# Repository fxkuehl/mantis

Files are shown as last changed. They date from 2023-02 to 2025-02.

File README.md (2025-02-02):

# Mantis hex ergo keyboard

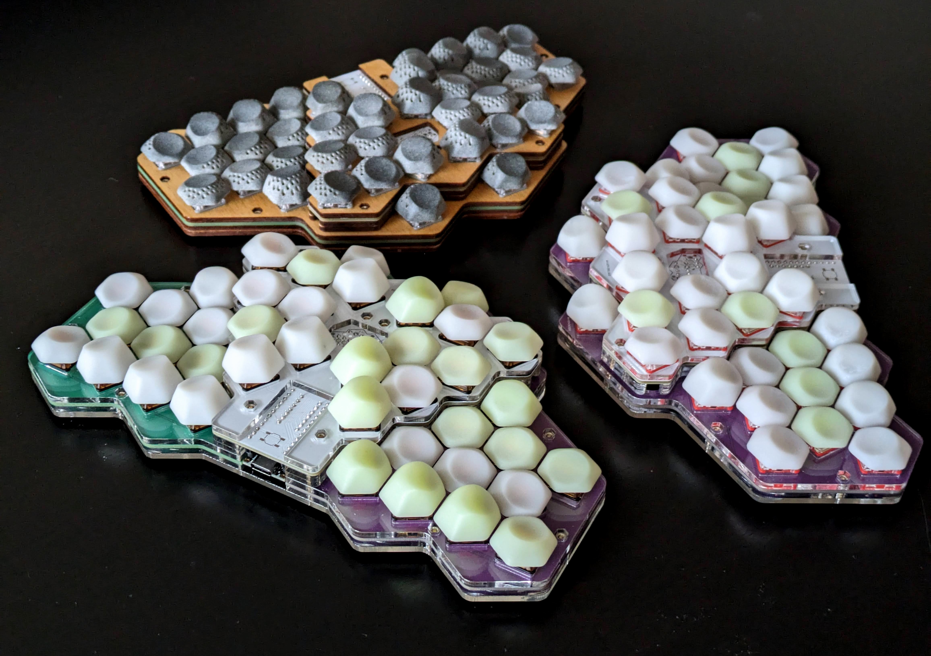
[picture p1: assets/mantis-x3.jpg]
>
>_Three different builds of Mantis v0.3.3, experimenting with different case and key cap materials_

## Contents

Mantis is an ergonomic keyboard designed around hexagonal keys.

This repository contains Ergogen, KiCad and OpenSCAD files for the PCBs, case and key caps, as well as a [build guide](./buildguide.md). You can print a [one-page reference and quick start guide](https://github.com/fxkuehl/mantis/blob/main/keymap.pdf) of the default keymap.

Mantis is approaching the end of the prototyping phase, currently at version v0.3.3. You can check the git history for older prototype versions.

Mantis v0.3.3 consists of three PCBs. Two identical [bottom PCBs](https://github.com/fxkuehl/mantis/raw/main/pcb/gerber/mantis-v0.3-bottom.zip) are reversible. The [central PCB](https://github.com/fxkuehl/mantis/raw/main/pcb/gerber/mantis-v0.3.3-top.zip) is stacked on top with M2 standoffs and headers to create an approximation of two tented, shallow key wells together with the [sculpted 3D printed keycaps](https://github.com/fxkuehl/mantis/tree/main/keycap) and the rotation of switches.

v0.3.3 also includes [DXF files](https://github.com/fxkuehl/mantis/tree/main/plates/v0.3.3) for laser-cut plates. I have built keyboards with 3mm thick acrylic and birch plywood plates, manufactured at Hot Pop Factory in Toronto.

## Build Guide

See the [complete build guide](./buildguide.md) for detailed instructions and all the tools, materials, and parts required.

## Firmware and Keymap

Firmware is available in my [QMK fork](https://github.com/fxkuehl/qmk_firmware/tree/mantis-vial-v0.3/keyboards/mantis). It is now based on the Vial version of QMK, so you can use the [Vial](https://get.vial.today/) GUI to customize the keymap more easily.

There is also a [ZMK shield](https://github.com/Silcantar/zmk-mantis). Thanks to Github user [Silcantar](https://github.com/Silcantar/) for creating it and [bringing](https://github.com/fxkuehl/mantis/issues/3) it to my attention.

# Concept

Mantis is a compact unibody ergo keyboard approximating 15° tented, shallow key wells using two layers of flat PCBs and custom sculpted hexagonal key caps. The hex grid naturally results in 30° hand rotation and aggressive column stagger. Hexagonal keys can rotate in 60° increments, which enables a decent approximation of key wells with only one or two unique keycap shapes. Existing 3x5+3 split layouts with 36 keys should be adaptable for this keyboard.

I recorded a short [YouTube video](https://www.youtube.com/watch?v=Rh3bqSVHcbg) to demonstrate the usability and comfort.

Layout diagram
>_Mapping QWERTY to the Mantis layout with staggered columns rotated 30° inwards_

Due to the way that columns of hexagonal keys are staggered, the index fingers only have five keys, while the pinkies can get one extra key that is comfortable to reach with splay. This requires some layout modifications when mapping QWERTY (or your favourite alternative layout) to this keyboard.

I wrote a [longer article](https://kbd.news/Mantis-Hexagonal-Keys-in-Ergonomic-Keyboards-2202.html) about the ergonomics of the layout and the motivation for trying hexagonal keys for the [kbd.news](https://kbd.news/) 2023 advent calendar.

## Evolution

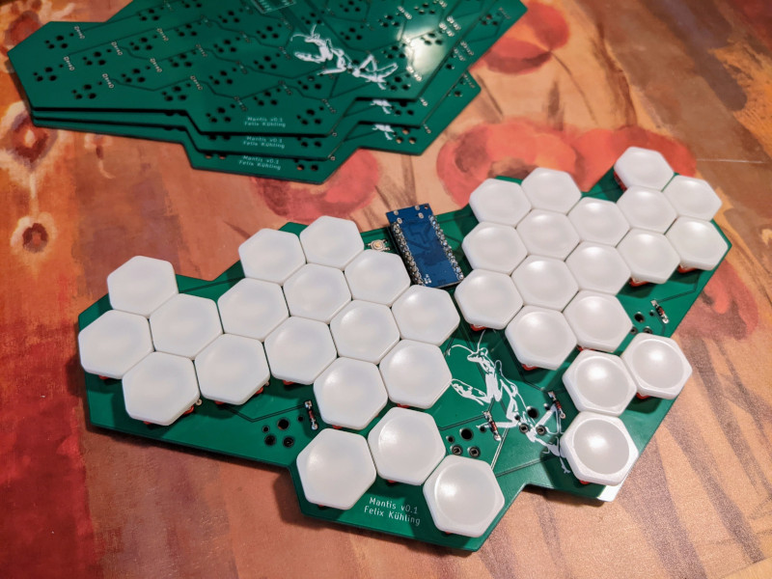
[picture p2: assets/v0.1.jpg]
v0.1
>

The first prototype v0.1 was inspired by [FK Keycaps HEX](https://fkcaps.com/keycaps/hex) keycaps. It served as a proof of concept of an ergonomic layout using hexagonal keys and gave me ideas for future revisions. This lead to the raised center and modified pinkie key layout in v0.2.

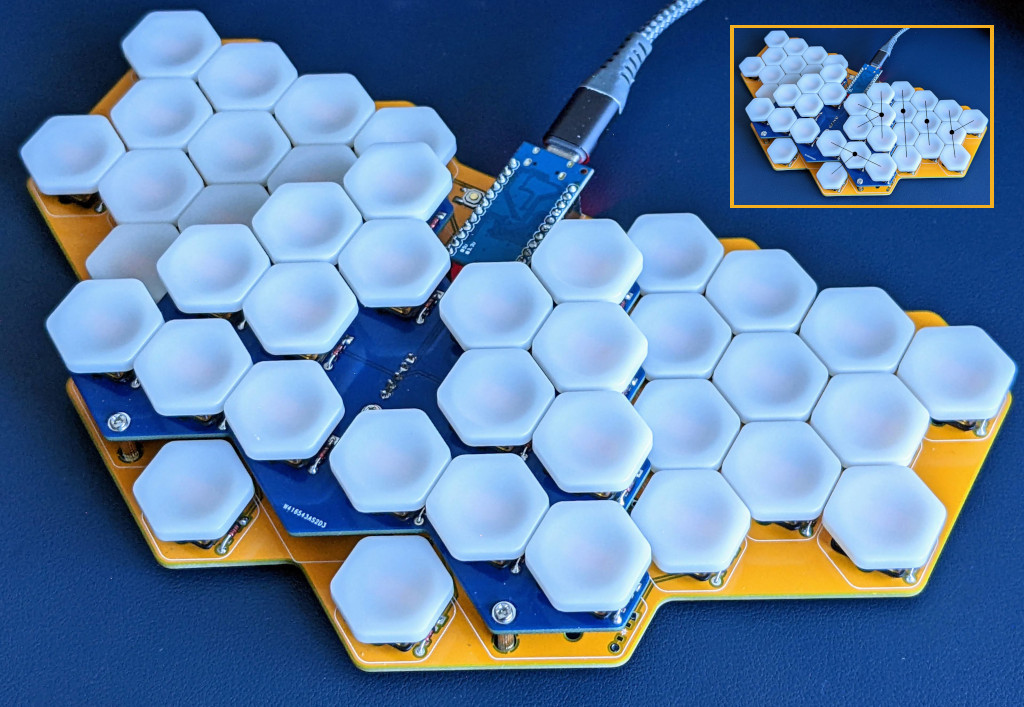
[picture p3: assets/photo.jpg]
v0.2
>

The raised center in v0.2 adds tenting and makes the index finger keys easier to reach. It also improves the spacing an usability of the thumb keys. I experimented with different mounting methods for stacking two PCBs, and tried different heights. Although usable and my daily driver for several months, this version still had problems with finger travel distance and accidental adjacent key presses.

These problems were addressed in v0.3 with a custom 3D-printed key profile and switch rotation. v0.3 also added per-key RGB backlight and a laser-cut sandwich case. The latest PCB and case version v0.3.3 has some refinements of the fit, changes the rotation of two keys on the upper PCB and adds support for RGB LEDs with 3.3V controllers.

The name Mantis comes from the shape of the PCB resembling a mantis head and the hexagonal keys suggesting compound eyes.

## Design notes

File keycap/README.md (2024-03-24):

# Mantis Keycap Recommendations

I created two types of keycaps:

- [Flat with 15° tilt](./keycap-v2-15-solid.stl) for most keys (24 keys per keyboard)
- [Tall with 28° tilt and flattened top](./keycap-v3-28-solid.stl) for top row and some of the thumb keys (16 keys per keyboard)

The two links above take you to the STL files to use for 3D printing. There are [additional](./keycap-v2-15.stl) [variants](./keycap-v3-28.stl) with small holes for letting LEDs shine through. Light resin keycaps are translucent enough without the holes. But they are needed if you want to see RGB lights with black resin, nylon or other opaque plastic keycaps.

There are also STL files that combine 10 keycaps in a single STL model, which may allow cheaper printing with some manufacturers, depending on their minimum per-part cost. This may negatively affect the quality of the print. See [this article](https://kbd.news/Mantis-keycaps-2157.html) for more details.

It is possible to build an entire keyboard with only the 15° keycaps. The top row will be a slightly longer reach, but it will still be quite comfortable to type on.

My original plan was to use the tall 28° keycaps on the bottom row as well. But I find that flat keys work better for curling my fingers and lead to less finger movement.

Finally, Mantis is still compatible with [FK Keycaps HEX](https://fkcaps.com/keycaps/hex) keycaps. These are the keycaps that inspired me to design this keyboard in the first place. But I would not recommend them for the most comfortable and efficient typing experience any more.

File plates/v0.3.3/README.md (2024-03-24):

# Mantis Case Plates

The cheapest way to build a Mantis is without a case. However, to protect the electronic components, and to get a more solid feel and sound, it is better to add a case. The case design for v0.3.3 uses laser cut plates of 3mm thickness. You can use different thickness, but that will also change the height of the standoffs and headers you need. I have built a few keyboard with clear acrylic plates, which looks nice with RGB LEDs and shows off the colors of the PCBs. I used birch plywood in another build for a slightly more rustic look.

To help with cost-effective manufacturing I created several DXF files in this folder that combine all the plates for [one](./plates.dxf), [two](./plates2x.dxf) or [four](./plates4x.dxf) keyboards in a single efficient layout. The four-keyboard layout fits on 60x90cm sheets of material and got the case cost for my latest builds down to about $50 CAD per keyboard from a local laser cutting shop.

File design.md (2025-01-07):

# Mantis Keyboard Design Evolution

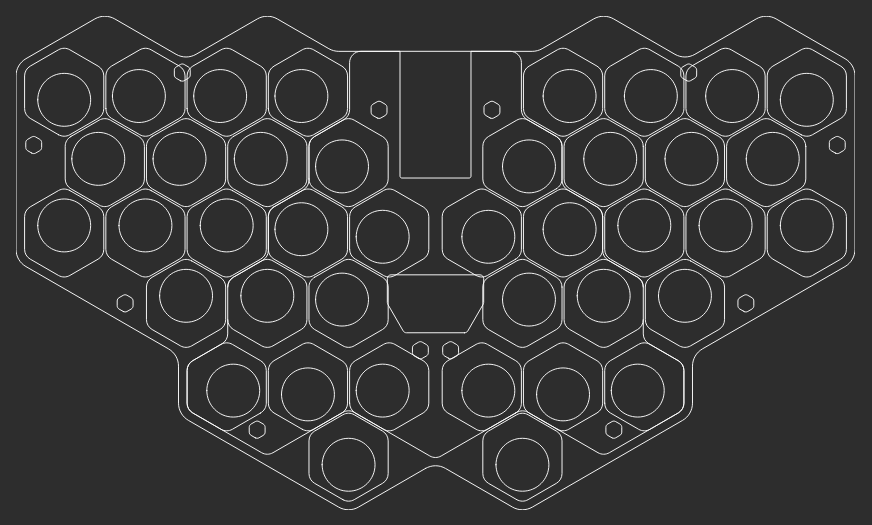
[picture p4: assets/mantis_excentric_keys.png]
>

>_Read the image captions below for the TL;DR ..._

When I started working on Mantis I was intrigued by the look of [hexagonal key caps](https://fkcaps.com/keycaps/hex) and their potential to create an ergonomic layout that follows from the hexagonal packing of keys. I learned to use [Ergogen](https://ergogen.cache.works/), [KiCad](https://www.kicad.org/), and eventually [OpenSCAD](https://openscad.org/), one prototype led to the next, and with v0.3 I may have created the lowest-profile, best-sounding, easiest to assemble tented unibody split keyboard with a key well that also happens to have hexagonal keys.

What all Mantis prototypes have in common are some of the original design ideas and methods used:

- Key spacing for [FK Keycaps Hex Keycaps](https://fkcaps.com/keycaps/hex)
- Unibody, 40 keys, compatible with 36-key layouts
- Column stagger and rotation of the keyboard halves resulting from the hexagonal key shape
- Layout and outlines designed with [Ergogen](https://ergogen.cache.works/)
- PCBs finished with [KiCad](https://www.kicad.org/)
- [QMK](https://qmk.fm/) firmware

Thanks to [PCBWay](https://www.pcbway.com/) for sponsoring v0.2 and v0.3 PCB production!

## February 2023 - v0.1: Proof of Concept

>v0.1

>_Hexagonal keys? Neat! I bet I can make an ergonomic unibody keyboard layout with that, where the column stagger and hand rotation follow organically from the shape of the keys. Let's build it and find out! Throw in some pinky splay too, while we're at it. With the keys resembling compound eyes, it kind of looks like the face of a praying mantis._

Version 0.1 was a proof of concept that hexagonal keys could be used to create an ergonomic unibody split keyboard layout that is actually usable. The shape of the keys results in a strong column stagger with the hands rotated 30° compared to a straight ortho-linear layout. The hexagonal packing of keys brings the columns closer together and results in the same distance of all keys from the home key of the same finger. Compared to "normal" 3x5 layouts, the index fingers lose one key that moves to the pinky instead. The pinkies get some splay in the top row.

Hot-swap sockets for switches and controller allowed easy reuse on later prototypes.

My [Reddit post](https://www.reddit.com/r/ErgoMechKeyboards/comments/116xqfr/first_prototype_of_my_ergonomic_keyboard_design/) prompted quite a spectrum of reactions (paraphrasing):

- Sexy!
- Something from an alien space ship ...
- Is this row staggered or column staggered?
- Where the heck is the home row?
- It makes my brain/hands hurt.
- Why would you want this?
- Nothing about this is ergonomic.

My verdict: v0.1 was actually usable. Coming from a Cantor Remix with 36 keys, I quickly adapted to the Mantis layout. The column stagger felt good. The pinky splay in the top row was a bit unfamiliar at first, but not bad. It took me a week or two to fully adjust to a modified Colemak-DH layout with 5 index-finger and 4 pinky keys. The large angle of the keyboard halves allows the wrists to be straight with the elbows resting on the arm-rests and the shoulders relaxed. A video of my typing looked relaxed with minimal hand and wrist movement.

v0.1 also revealed a few problems in use:

- The fourth thumb key was unusable (as expected)
- The other three thumb keys were too close together in their arc
- The outer home row pinky key was uncomfortable to reach
- Finger travel distance within the columns was quite large, though not excessive with only 3 rows to reach
- The flat key profile can lead to accidental adjacent key presses (I had the same problem with MBK key caps on my Cantor Remix)

## March 2023 - v0.2: Mantis Goes 3D

>v0.2

> _v0.1 was actually usable and comfortable. The pinky splay worked, but the outer home row pinky keys were a bit uncomfortable to reach, so v0.2 rearranges the pinky keys. Also the thumb keys were a bit close together and the optional 4th thumb key wasn't usable. Raising the center keys can fix those thumb cluster issues while adding some tenting and an approximation of a key well all at once. There are more things I want to try, but this is enough change for another prototype. Stacking two PCBs allows playing with some fun color schemes! Not all mantises are green ..._

v0.2 takes some inspiration from the [Thumbs Up!](https://www.reddit.com/r/ErgoMechKeyboards/comments/z4qdgr/thumbs_up_v2_keyboard/) keyboard. By raising the center keys, an approximation of a key well is created. Going into the 3rd dimension also offers a neat solution to the thumb cluster issues without compromising on the hexagonal key layout: By lowering the front-most thumb key, it creates a larger separation of the three keys in the arc and it makes the fourth thumb key above it usable. Other benefits:

- Index fingers can reach their keys more easily
- 10mm rise results in about 15° tenting angle to make the wrists more comfortable
- Home position is easy to find by touch

v0.2 also changed the layout of the pinky keys to avoid uncomfortable stretching to the side, which resulted in a slightly more compact layout. The bottom PCB still has all the switch footprints, so it could still be used to build a flat keyboard.

I built two prototypes to experiment with different heights and assembly methods. The top and bottom PCBs can be connected with only the headers. Optional M2 stand-offs can be used to adjust the height and make the assembly more stable. A high-profile version with 12mm rise uses 8mm headers. Adding 10mm stand-offs made it sturdier. A low-profile version with 6.6mm rise uses low profile sockets, diode legs as pins and 5mm stand-offs. The ideal may be somewhere in the middle using 8mm stand-offs and maybe 5mm headers from Adafruit.

For this version I created and over time refined a unique keymap loosely based on my earlier Kolibri layout. It takes advantage of the hexagonal layout for the positioning of arrow keys and F-keys, with numbers on the home row and the ability to switch between modified QWERTY and Colemak-DH layouts with a key combination.

## July 2023 - v0.3: Sculpted Key Caps, RGB, Case Plates

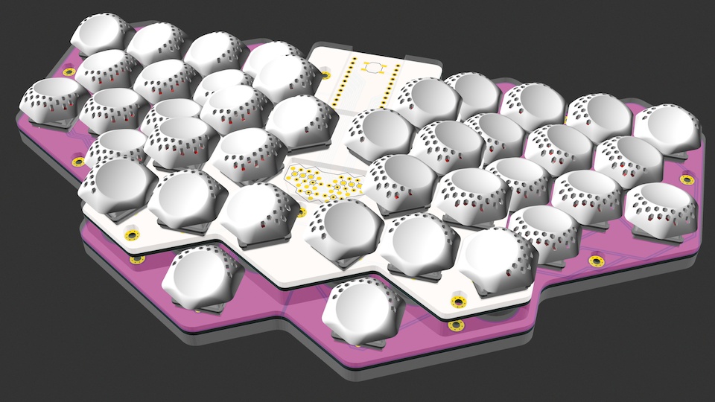
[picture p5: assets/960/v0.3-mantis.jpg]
v0.3 render
>

> _v0.2 was pretty good for daily use. I actually built two of them for home and the office, and I even took one with me while travelling. But there are some problems left to fix, and bling that needs to be added. So here comes a big redesign with lots of attention to detail: Sculpted keys optimized for touch typing, per-key RGB, an acoustically optimized acrylic case, and a split/reversible bottom PCB to reduce cost. Since I already learned OpenSCAD to create the key cap, why not render a preview of the whole keyboard with it? BTW, there is only a single key cap profile here. The shallow key well is achieved by rotating the switches in 60° increments. Try that with square keys!_

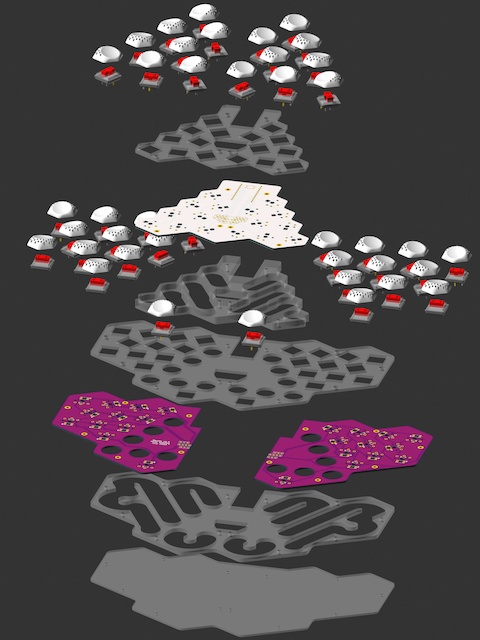
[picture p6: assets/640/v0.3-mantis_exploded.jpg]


The original flat Hex key caps from FK Keycaps were designed for [music keyboards](https://fabacademy.org/2020/labs/opendot/students/sol-bekic/projects/keyboard/) and [macro pads](https://fkcaps.com/keyboards/0xC.pad). While v0.3 is still compatible with the flat Hex key caps, fixing the problems with accidental key presses and finger travel distance called for the design of 3D-printable [sculpted key caps](https://github.com/fxkuehl/mantis/blob/main/keycap/keycap.stl) with features optimized for ergonomic touch typing:

- Smaller target area with a spherical dish and defined edge
- Tilted, excentric dish oriented toward the direction of finger movement to reduce finger travel and ensure smooth key actuation by directing force towards the center of the switch stem
- Sloping sides to create more separation between adjacent keys, reducing accidental key presses
- Smooth transition from the front of the dish to the edge of the key to make it comfortable for the thumbs

The key profile is designed in OpenSCAD to make it parametric and easy to adjust and optimize. Using the general polyhedron primitive makes it possible to describe the organic shape with curved, sloping sides creating a smooth transition from the rim of the tilted spherical dish to the rounded hexagon outline of the key. A Minkowski sum with a half sphere is used to generate an even wall thickness. To allow per-key LEDs to work with opaque materials, the outside slope near the switch's LED hole features perforations to let light shine through and reflect indirectly in all key orientations.

The tilt angle of the spherical dish is 15° to match the intended tenting angle of the keyboard on the home row. On the other rows, the keys are rotated differently to match the direction of finger travel. This is achieved by rotating the switches and their PCB footprints in 60° increments. Thus only a single key cap profile is sufficient to approximate a shallow key well. Even with the sculpted profile and a 15° tilt, the keys are only 2mm taller than the original flat Hex key caps.

In addition to per-key RGB backlight, v0.3 adds a case by sandwiching laser-cut plates with the PCBs, held together with M2 stand-offs. The mid-layers are designed to optimize the acoustics of the keyboard. The resonant spaces in the top and bottom of the case are connected through openings in the PCBs and switch plates such that each keyboard half has a long channel (~50cm) winding under its keys, open to the outside on one end. The low resonant frequency (~170Hz) is meant to modulate the sound of the key strokes for a "thocky" effect. To make a continuous channel possible, hot-swap sockets had to be sacrificed; v0.3 supports only soldered switches.

The bottom PCB is split and reversible to reduce manufacturing cost. The diodes and LEDs are surface mounted on the bottom to allow the switch plates to be flush with the top of the PCBs. The controller is mounted underneath the top PCB, so it is completely hidden inside the case. The pads of the headers connecting the PCBs masquerade as a layout diagram depicting the home position and finger assignment on the silkscreen. With all the headers concentrated in the center, stand-offs and/or plates are required for stability. The stand-offs also serve as GND connection between the PCBs, required for the LEDs to work.

The LED footprints are chained to give some options for building keyboards with fewer or more LEDs:

- 6: Only the six top center keys, including the index finger home keys
- 16: Only the center PCB keys
- 40: All keys

## What's Next?

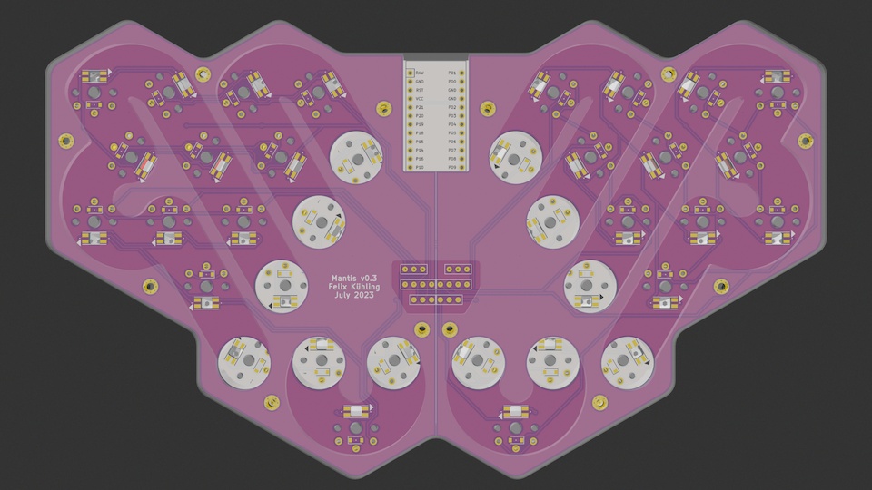
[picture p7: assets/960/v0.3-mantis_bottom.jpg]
Bottom view of v0.3
>

>_I expect to use v0.3 for a while and build a few of them as gifts for friends and family members who have expressed interest. I hope to see a few more brave enthusiasts who use the source and build their own Mantis boards. The next version may have a 3D-printed case and an integrated pointing device._

There are a few things to experiment with in v0.3 that don't need a big redesign. The sculpted key cap design is parametric. Depending on how v0.3 feels in daily use, I may play with those parameters, maybe use a few different key cap profiles on different keys. I may also change the design that lets LEDs shine through, experimenting with different materials and holes that don't penetrate all the way to the top of the key cap.

I may try out wooden case plates for a different look and sound. Maybe I can come up with a low-profile, low-noise version of the case.

For the next big revision my major open TODO-list item is an integrated pointing device. A track point or tiny trackball should fit easily. A bigger trackball or a small Cirque trackpad may be doable, though I would have to sacrifice two thumb keys to keep the overall compact layout.

I also want to look into a 3D-printed case design for a more finished look and potentially more cost effective production.

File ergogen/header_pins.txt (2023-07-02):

Pro-Micro and header footprint pin numbering

Pad Pin  MCU   Headers   Side
-----------------------------
 1  RAW                   R
 2  GND  GND
 3  RST  RST
 4  VCC  VCC    VCC
 5  P21         R3
 6  P20         R2
 7  P19  M_C1   M_C1
 8  P18  M_C2   M_C2
 9  P15  M_C3   M_C3
10  P14  M_C4   R1
11  P16  M_C5   RT
12  P10         DIN
-----------------------------
13  P01  R3     R3        L
14  P00  R2     R2
15  GND  GND
16  GND  GND
17  P02  R1     R1
18  P03  RT     RT
19  P04  C1     C1
20  P05  C2     C2
21  P06  C3     C3
22  P07  C4     VCC
23  P08  C5     DOU
24  P09  DIN    DIN

Header Pins

Raised:
C3  C2  C1          C1  C2  C3
R3  R2  R1  RT  RT  R1  R2  R3
    VCC DOU DIN --- DIN VCC

Main-Split:
C3  C2  C1
R3  R2  R1  RT
    VCC DIN DOU

Header Pads

21  20  19           7   8   9
13  14  17  18  11  10   6   5
    22  23  24  --- 12   4

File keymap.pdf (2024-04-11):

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
## Del

↹

Ctrl

AltGr

⇧

### Sym

Ctrl

⚜

AltGr

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
Scrl

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
### Esc

Ins

←

## Del

⎙

### Caps

⌨

### Vol+

### Mute

Vol- ⎵

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
### Home

⬅

⬆

➡

### End

### Page↑

⬇

### Page↓

### Scrol

### Media

### Prev Play

## Next

Here is a really-quick intro to the Mantis keyboard layout. Don't let the hexagonal keys confuse you! The diagram above highlights the rotated and staggered columns with alternating shading for each finger. Dark circles indicate the home keys for each digit.

The letter keys are mostly QWERTY but the index fingers are missing one key. Therefore J and B are moved to the pinkies. Space is on the right thumb home key. To provide the same functionality as a full-size keyboard, each key performs multiple jobs (colored legends):

Black: Alpha layer for normal letters with a (nearly) QWERTY layout
Purple: Locked Editing and Numpad layer
Green: Momentary Symbol layer with numbers and symbols
Red: Momentary Function layer with function, navigation and editing keys
Blue: Modifiers Ctrl, Win/OS (⚜), Alt (⎇), Shift (⇧), AltGr

Activate the Symbol and Function layer by holding Sym or Fn respectively, just like you'd hold Shift to type UPPERCASE. Modifiers are also (mostly) activated by holding a key, rather than tapping it. Fn+X toggles the Editing and Numpad layer, relieving your thumbs.

The Symbol layer has numbers on the home row and most shifted number symbols above. The Function layer has a navigation cluster on the right, editing keys on the left, F1-F12 across the top row. There are also six volume and media control keys. The top-right row on the Numpad layer controls the RGB backlight animations (hold Shift to decrease settings): mode, hue, saturation, value, speed, on/off.

Common combos of layers and modifiers are comfortable without twisting or moving your hands. You won't need Shift on the Symbol layer or AltGr on the Fn layer. Alt can be used as a one-shot mod. E.g. if you need to type Alt+1, tap Alt, then hold Sym and tap 1. The Symbol layer has a second AltGr on the left index to combine with right thumb symbols.

Customize the keymap for your needs with Vial (https://get.vial.today/). It updates the keymap on-the-fly and stores it on the keyboard itself. You'll have your custom keymap with you wherever you take your keyboard. Happy typing!

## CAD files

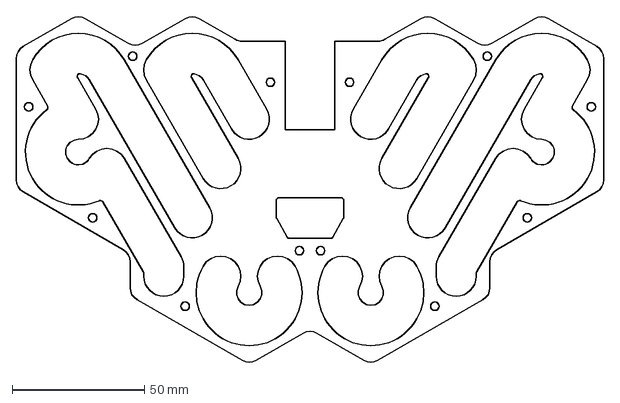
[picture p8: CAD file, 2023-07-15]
keycap/sound_plate_main.dxf
222.0 x 131.1 mm

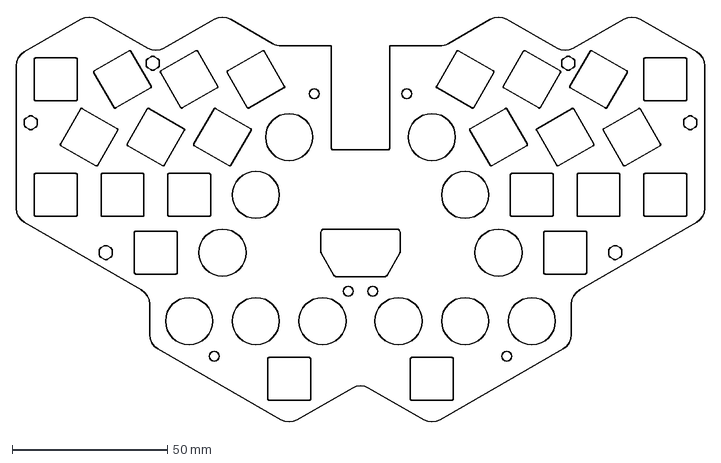
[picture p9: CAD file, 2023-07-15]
keycap/plate_main.dxf
222.0 x 131.1 mm

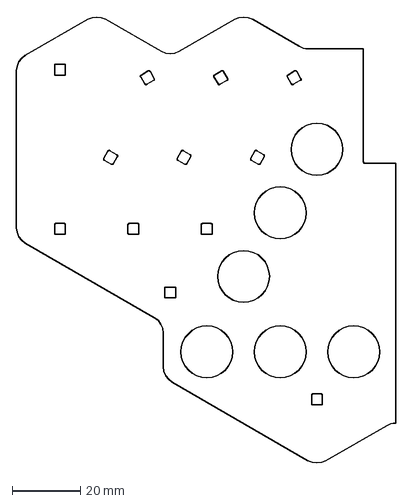
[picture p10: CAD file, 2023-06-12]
keycap/main_split.dxf
111.0 x 131.1 mm

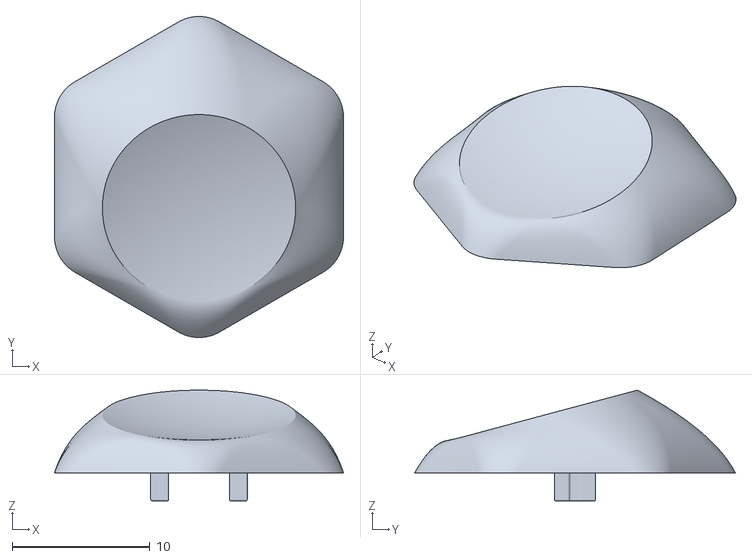
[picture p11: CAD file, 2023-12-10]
keycap/keycap-v2-15-solid.stl
21.0 x 23.3 x 8.02

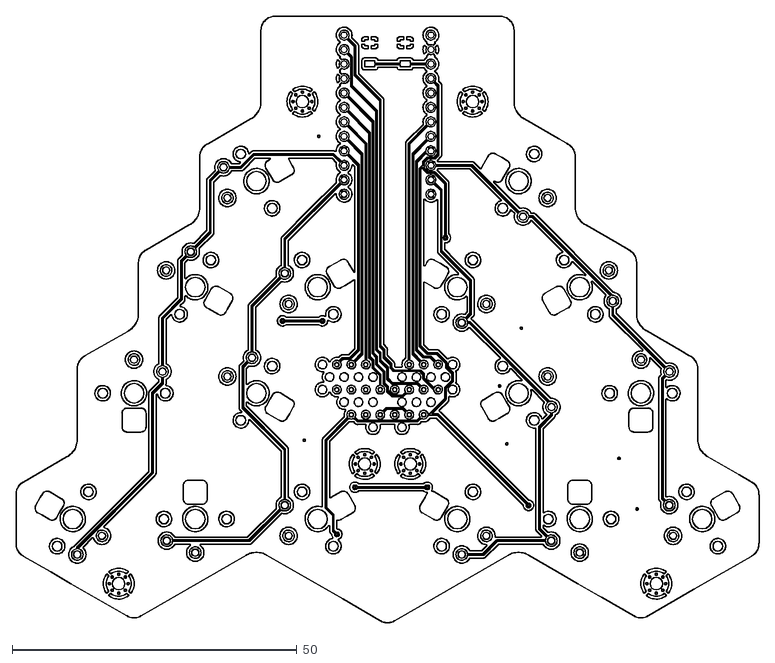
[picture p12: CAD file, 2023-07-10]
keycap/pcbs/mantis_raised_leds-F_Cu.dxf
130.4 x 106.5

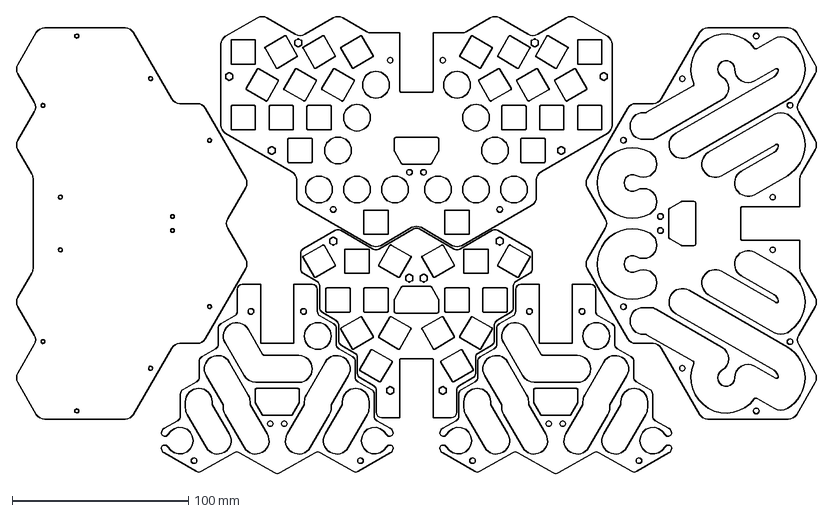
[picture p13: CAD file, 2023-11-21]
plates/v0.3.3/plates.dxf
454.0 x 259.6 mm

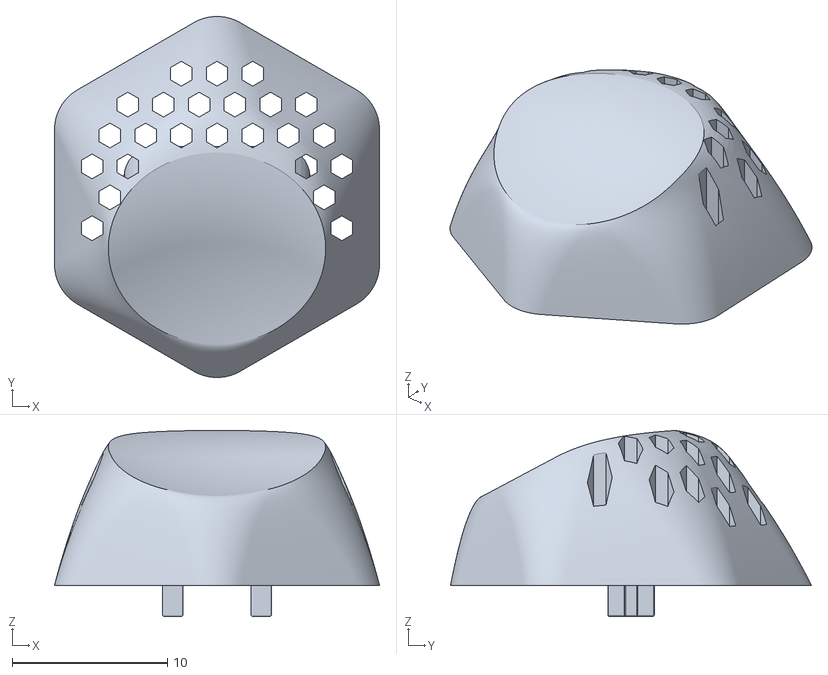
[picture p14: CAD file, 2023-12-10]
keycap/keycap-v3-28.stl
21.0 x 23.3 x 12.0

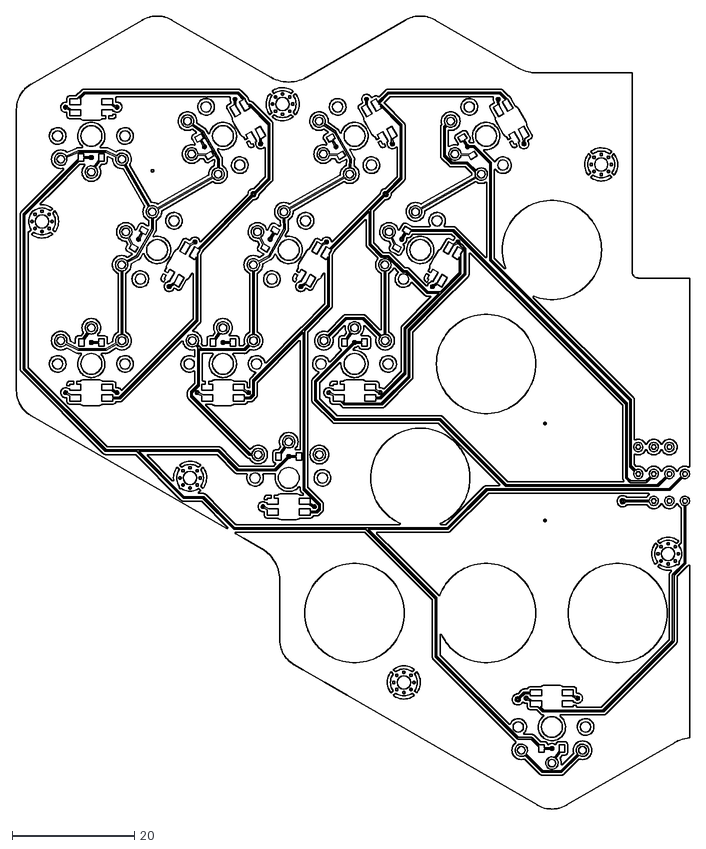
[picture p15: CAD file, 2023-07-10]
keycap/pcbs/mantis_reversible_split_leds-B_Cu.dxf
110.0 x 129.6

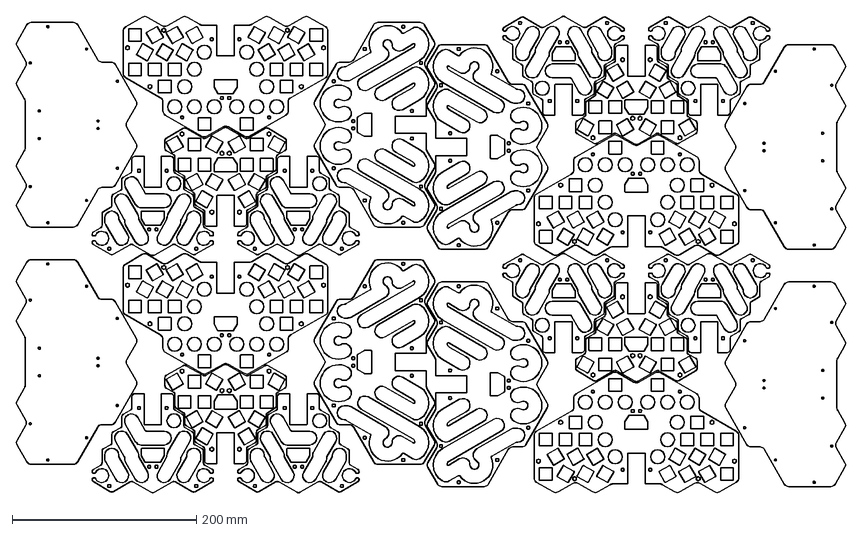
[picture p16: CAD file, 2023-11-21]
plates/v0.3.3/plates4x.dxf
899.5 x 517.1 mm

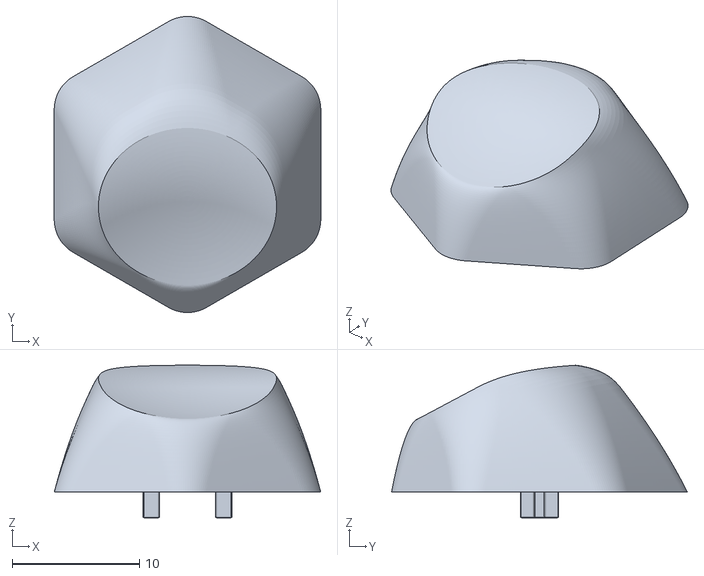
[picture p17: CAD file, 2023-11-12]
keycap/keycap-v3-28-solid.stl
21.0 x 23.3 x 12.0

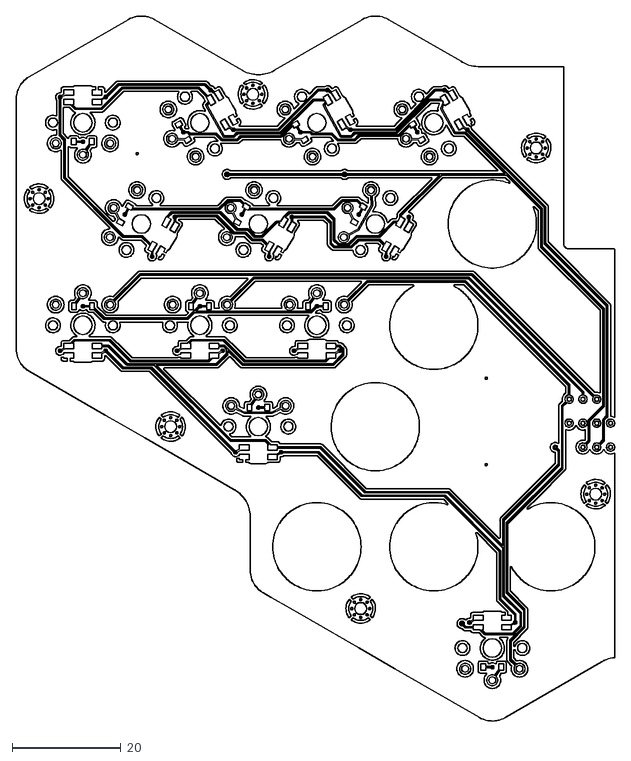
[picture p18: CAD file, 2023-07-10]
keycap/pcbs/mantis_reversible_split_leds-F_Cu.dxf
110.0 x 129.6

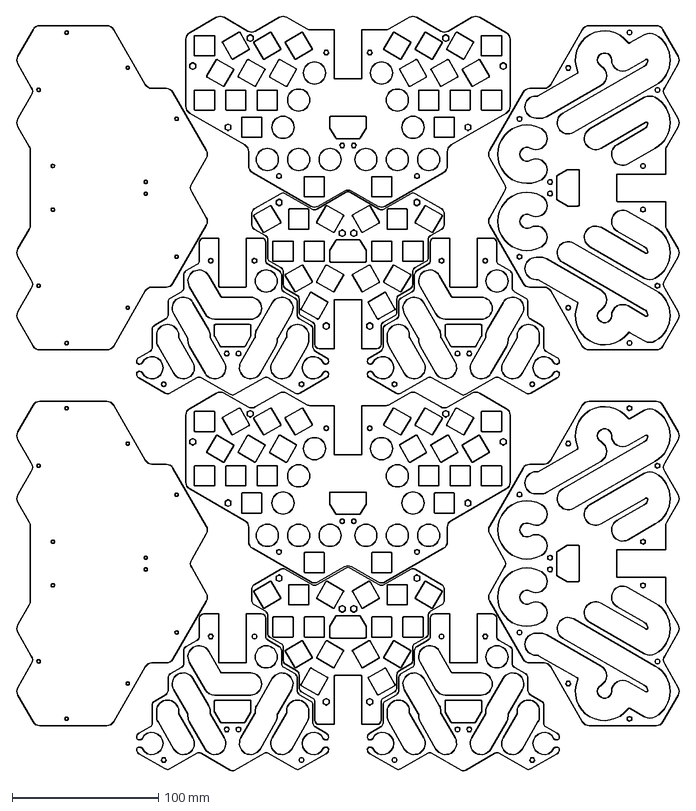
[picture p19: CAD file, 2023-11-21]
plates/v0.3.3/plates2x.dxf
454.0 x 516.9 mm

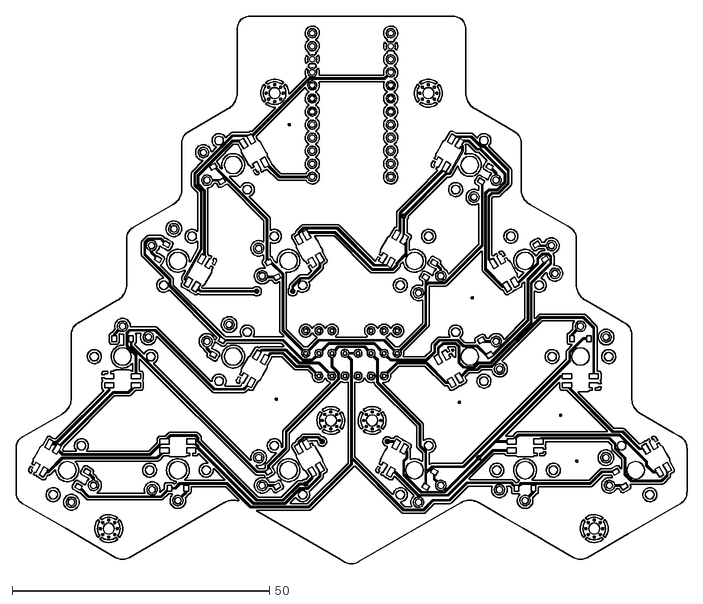
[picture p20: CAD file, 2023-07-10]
keycap/pcbs/mantis_raised_leds-B_Cu.dxf
130.4 x 106.5

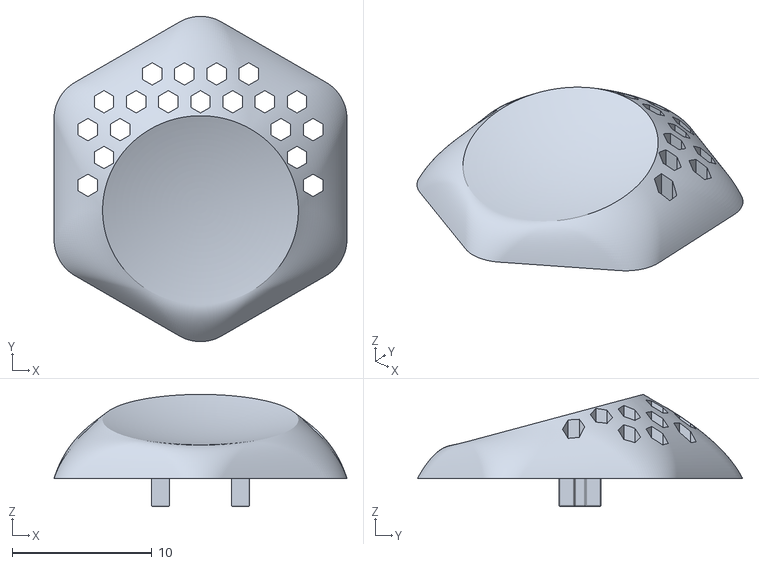
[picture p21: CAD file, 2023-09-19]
keycap/keycap-v2-15.stl
21.0 x 23.3 x 8.02

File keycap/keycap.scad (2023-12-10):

// Angular resolution
$fa = 2;
// Generate several keys as one part for lower printing cost (see https://3d.jlcpcb.com/help/article/213-Connected-Parts-Printing-Guide)
n_keys = 1;
// Whether to render RGB LED cutouts in the keycaps
$rgb = true;
// Whether to use a minkowski sum for more consistent thickness
$minkowski = false;

// Key parameters:
// Rotation of the stem
$rot = 0;
// Tilt angle of the keycap surface
$tilt = 15;
// Slope angle of the dish at the rim
$slope = 15;
// Droop from the stem interface to the base of the key
$droop = 1.5;
// Rise from the stem interface to the front rim of the dish (minus thickness)
$rise = -0.5;
// Approximate thickness of the wall
$thickness = 1.4;
// Width of the hexagonal key
$key_width = 20.96;
// Diameter of the spherical dish
$dish_diam = 14;
// Fillet radius
$fillet = 3;
// Maximum dish excentricity (tilt / 7.5)
$max_exc = 2.5;
// Start soft-clamping Z at
$clamp_z1 = 8.25;
// Clamp infinity Z to
$clamp_z2 = 10.25;

// How far the keys are pressed down (0-3mm)
travel = 0.1;
// Mantis plate explosion offset
$explode = 0;
// Set by files including this one
no_key = false;
// Show the key
show_key = true;
// Show the switch
show_switch = false;
// One key sliced and exploded to show wall thickness
show_sliced_key = false;
// Print some key stats
$print_stats = false;

use <utils.scad>

cos30 = cos(30);
function fillet_unit_hex_segment(r, a) = a < r*30 ?
    // arc segment
    [-r*sin(a/r), r*cos(a/r) + (1 - r)/cos30, 0] :
    // linear segment
    let (xr30 = -r/2, yr30 = (1 - r)/cos30 + r*cos30,
         dx = -(1 - r) / ((1 - r)*60),
         dy = -(1 - r)/(2*cos30) / ((1 - r)*60))
        [xr30 + dx * (a - r*30), yr30 + dy * (a - r*30), 0];

function fillet_unit_hex_point(r, a) = let (b = (a + r*30) % 60 - r*30)
    rotate_z(fillet_unit_hex_segment(r, b), a-b);

module fillet_hexagon(R, r, h, da=$fa) {
    steps = floor(360/da);
    
    points_lower = [for (a = [0 : da : (steps-1) * da])
        fillet_unit_hex_point(r/R, a)*R
    ];
    points_upper = [for (a = [0 : da : (steps-1) * da])
        fillet_unit_hex_point(r/R, a)*R + [0, 0, h]
    ];
    points = concat(points_lower, points_upper);

    face_bot = [for (i = [0 : 1 : steps-1]) i];
    face_top = [for (i = [0 : 1 : steps-1]) steps*2 - 1 - i];
    faces_rim = [for (i = [0 : 1 : steps-1])
        [(i + 1) % steps, i, steps + i, steps + (i + 1) % steps]
    ];
    faces = concat([face_bot, face_top], faces_rim);

    polyhedron(points, faces);
}

// Linear interpolation
// Interpolates a quantity x between two values x1 and x2 using
// a parameter b such that x(b=0) == x0, x(b=1) == x1. For b
// outside the interval [0, 1] it's a linear extrapolation.
function interpolate(x0, x1, b) = x0 * (1 - b) + x1 * b;

// Fillet Hexagon Cone
// R1/2: Lower/Upper major radius
// r1/2: Lower/Upper fillet radius
// exc: excentricity at top
// tilt: tilt angle of the top
// slope: slope at the inside rim of the dish
// h: padding height
// offset: Shrink/expand outline along the normal vector
module fillet_hexagon_cone(R1, R2, r1, r2, exc, tilt, slope, h, offset, da=$fa) {
    steps = floor(360/da);

    // y-z coordinates of front and back perimeter and rim for interpolation
    yf1 = -R1/cos30 + r1*(1/cos30 - 1);
    zf1 = 0;
    yf2 = -R2/cos30 + r2*(1/cos30 - 1) - exc;
    zf2 = h;
    yb1 = -yf1;
    zb1 = 0;
    yb2 = yf2 + 2*R2*cos(tilt);
    zb2 = zf2 + 2*R2*sin(tilt);
    D0 = 2*yb1;

    // Average slopes dz / dy front and back
    dyf = yf2 - yf1;
    dzf = zf2 - zf1;
    dyb = yb2 - yb1;
    dzb = zb2 - zb1;
    dzdyf = dzf / dyf;
    dzdyb = dzb / dyb;

    // parabola for interpolating zf-coordinates that is
    // 0 at b=0
    // 1 at b=1
    // has slope s at b=1 (the rim) that matches the slope of the dish
    sf = tan(tilt-slope) / dzdyf;
    af = sf - 1;
    bf = 2 - sf;

    // parabola for interpolating yb-coordinates that is
    // 0 at b = 0
    // 1 at b = 1
    // has slope s at b=0 (the outside edge) that matches the slope at the
    // front edge of the key
    sb = -0.5 * dzdyb;
    ab = 1 - sb;
    bb = sb;

    // slope (dy/dz) at the back rim
    sb1 = -(2*ab + bb) / dzdyb;
    // angle to vertical of the slope at the back rim
    asb = atan(sb1);
    // angle to vertical of the dish at the back rim
    adb = 90 - tilt - slope;
    // z-value where the offset dish and back slope intersect
    zbmax = zb2 - offset * cos(asb) / tan((asb + adb) / 2);
    qbmax = (zbmax - zb1) / dzb;

    // maximum y-value (approx.) at front slope to avoid self-intersecting
    qfmax = offset > 0 ? 0.8 : 1;

    steps_cone = max(3, floor(steps / 15));
    n_points_cone = [for (b = [0 : 1/steps_cone : 1]) steps];
    points_cone = [for (b = [0 : 1/steps_cone : 1]) each
        let (qf = b * qfmax,
             qb = b * qbmax,
             b2f = qf * (af*qf + bf),
             b2b = qb * (ab*qb + bb),
             r = interpolate(r1, r2, b2f),
             yf = interpolate(yf1, yf2, qf),
             zf = interpolate(zf1, zf2, b2f),
             yb = interpolate(yb1, yb2, b2b),
             zb = interpolate(zb1, zb2, qb),
             ynf = (2*af*qf + bf) / dyf,
             znf = -1.0 / dzf,
             snf = offset / sqrt(ynf^2 + znf^2),
             ynb = 1.0 / dyb,
             znb = (-2*ab*qb - bb) / dzb,
             snb = offset / sqrt(ynb^2 + znb^2),
             yof = yf + ynf * snf,
             zof = zf + znf * snf,
             yob = yb + ynb * snb,
             zob = zb + znb * snb,
             w = yob - yof,
             D = sqrt((yob - yof)^2 + (zob - zof)^2),
             ro = max(0, r - (1 - b2f) * (D0 - D)/2),
             R = D/2 * cos30 + ro * (1 - cos30),
             t = atan2(zob - zof, yob - yof),
             shift = yof + D/2)
        [for (a = [0 : da : (steps-1) * da])
            scale_x(
                rotate_x_around(fillet_unit_hex_point(ro/R, a)*R,
                                t, [0, -D/2, 0]), offset > 0 ? w/D : 1) + [0, shift, zof]
        ]
    ];

    // Spherical dish with specified slope at the rim, tilted forward by the
    // specified angle
    dish_radius = R2 * sqrt(1 + 1/tan(slope)^2);
    dish_depth = dish_radius * (1 - cos(slope));
    //echo(true_excentricity=(exc + (1-cos(tilt))*R2 - sin(tilt)*dish_depth));
    offset_radius = dish_radius + offset;

    steps_dish = max(2, floor(slope / da));
    da_dish = slope / steps_dish;
    n_points_dish = [for (b = [slope-da_dish : -da_dish : 0])
        max(1, ceil(steps * sin(b) / sin(slope)))];
    points_dish = [for (i = [0 : 1 : steps_dish - 1]) each
        let (b = (steps_dish - i - 1) * da_dish, n = n_points_dish[i], da = 360 / n)
        [for (j = [0 : 1 : n-1]) let (a = j * da)
            rotate_x_around(offset_radius*sin(b)*[-sin(a), cos(a), 0] +
                            [0, 0, offset_radius*(1-cos(b)) - dish_depth - offset],
                            tilt, [0, -R2, 0]) + [0, -exc, h]
        ]
    ];

    points = clamp_z_exp(concat(points_cone, points_dish), $clamp_z1 - offset, $clamp_z2 - offset);
    n_points = concat(n_points_cone, n_points_dish);

    face_bot = [for (i = [0 : 1 : steps-1]) i];
    faces_cone = concentric_faces(steps_cone + steps_dish, n_points);
    faces = concat([face_bot], faces_cone);

    polyhedron(points, faces, convexity=2);
    
    // Some stats
    if ($print_stats) {
        point_center = points_dish[len(points_dish)-1];
        total_height = h + 2*R2*sin(tilt);
        mounted_height = total_height - h + $thickness;
        target_depth = -point_center.y/tan(tilt) - (point_center.z - h)
                     - $thickness;
        echo(total_height=total_height, mounted_height=mounted_height,
             dish_depth=dish_depth, target_depth=target_depth,
             center_y=point_center.y, center_z=point_center.z);
    }
}

// How far the the switch can be inserted into the bottom of the key
function min_rise() = let (
    exc = min($max_exc, $tilt/7.5),
    dish_radius = $dish_diam/2 * sqrt(1 + 1/tan($slope)^2),
    dish_depth = (1.0-cos($slope))*dish_radius,
    front_offset = 0.5,
    mid_offset = rotate_x_around(
        [0, -3, -dish_depth], $tilt,
        [0, -exc - $dish_diam/2, 0]).z)
    -min(front_offset, mid_offset);

module choc_peg() {
    r = 0.1;
    module cross_section() {
        offset(r = -2*r) offset(delta = r) polygon([
    [ 0.65,-1.5], [ 0.65,-0.4], [ 0.449,-0.4], [ 0.449,0.4], [ 0.65,0.4], [ 0.65,1.5],
    [-0.65,1.5], [-0.65,0.4], [-0.449,0.4], [-0.449,-0.4], [-0.65,-0.4], [-0.65,-1.5]
        ]);
    }
    translate([0, 0, r]) minkowski() {
        linear_extrude(height = 4 - 2*r, convexity = 2) {
            cross_section();
        }
        half_sphere(r, $fa = 360/$fn);
    }
}
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

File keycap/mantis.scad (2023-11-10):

// Including it with use <> prevents global variables set in the GUI
// from propagating into keycap.scad.
include <keycap.scad>

// Angular resolution of keycap surface
$fa = 2;

// Whether to render RGB LED cutouts in the keycaps
$rgb = true;
// Mantis plate explosion offset
$explode = 0;

// Prevent rendering key in keycap.scad
no_key = true;

// Show switches
show_switch = true;
// Show keys
show_key = true;
// Model of mantis sound channels
show_sound = false;

// Mid layer height
mid_layer_height = 6;
// Tilt angle for home keys
tilt1 = 15;
// Rise of the home keys
rise1 = -0.5;
// Tilt angle for top row keys
tilt2 = 28;
// Rise of the top row keys
rise2 = 2.9;
// Tilt angle for bottom row keys
tilt3 = 15;
// Rise of the top bottom keys
rise3 = -0.5;

// Render PCBs accurately
render_pcbs = false;
// Left bottom PCB color
bottom_color1 = "purple";
// Left bottom PCB color
bottom_color2 = "lime";
// Top PCB color
top_color = "white";

module pcb(outline, prefix, thickness, mcolor, scolor, alpha = 1) {
    d = 0.05;
    module holes() {
        intersection() {
            import(str(prefix, "-B_Silkscreen.dxf"), convexity = 10);
            import(str(prefix, "-B_Mask.dxf"), convexity = 10);
        }
    }
    module bulk() {
        difference() {
            offset(delta = -0.05) import(outline, convexity = 10);
            holes();
        }
    }
    color("Coral") translate([-254, 127, thickness - 1.5 * d])
        render(convexity = 10)
        linear_extrude(height = d, convexity = 10) difference() {
            import(str(prefix, "-F_Cu.dxf"), convexity = 10);
            holes();
        }
    color("Coral") translate([-254, 127, 0.5 * d])
        render(convexity = 10)
        linear_extrude(height = d, convexity = 10) difference() {
            import(str(prefix, "-B_Cu.dxf"), convexity = 10);
            holes();
        }
    color(scolor) translate([-254, 127, thickness - 0.5*d])
        render(convexity = 10)
        linear_extrude(height = d, convexity = 10) difference() {
            import(str(prefix, "-F_Silkscreen.dxf"), convexity = 10);
            holes();
        }
    color(scolor) translate([-254, 127, -0.5*d])
        render(convexity = 10)
        linear_extrude(height = d, convexity = 10) difference() {
            import(str(prefix, "-B_Silkscreen.dxf"), convexity = 10);
            holes();
        }
    color("Gold") translate([-254, 127, thickness - 1.5*d])
        render(convexity = 10)
        linear_extrude(height = 1.5*d, convexity = 10) intersection() {
            difference() {
                import(str(prefix, "-F_Cu.dxf"), convexity = 10);
                holes();
            }
            import(str(prefix, "-F_Mask.dxf"), convexity = 10);
        }
    color("Gold") translate([-254, 127, 0])
        render(convexity = 10)
        linear_extrude(height = 1.5*d, convexity = 10) intersection() {
            difference() {
                import(str(prefix, "-B_Cu.dxf"), convexity = 10);
                holes();
            }
            import(str(prefix, "-B_Mask.dxf"), convexity = 10);
        }
    color("DarkSlateGrey", alpha = 0.95) translate([-254, 127, d])
        render(convexity = 10)
        linear_extrude(height = thickness-2*d, convexity = 10)
        bulk();
    color(mcolor, alpha) translate([-254, 127, thickness - 1.5*d])
        render(convexity = 10)
        linear_extrude(height = 1.5*d, convexity = 10) difference() {
            bulk();
            import(str(prefix, "-F_Mask.dxf"), convexity = 10);
        }
    color(mcolor, alpha) translate([-254, 127, 0])
        render(convexity = 10)
        linear_extrude(height = 1.5*d, convexity = 10) difference() {
            bulk();
            import(str(prefix, "-B_Mask.dxf"), convexity = 10);
        }
}

function opacity(mcolor) = (mcolor == "white" || mcolor == "black") ? 0.95 : mcolor == "yellow" ? 0.5 : 0.75;

module mantis() {
    module base() {
        linear_extrude(height = 1.61, convexity = 10)
            translate([-254, 127]) import("base.dxf", convexity = 10);
    }
    module sound_plate_main() {
        linear_extrude(height = 2.99, convexity = 10)
            translate([-254, 127]) import("sound_plate_main.dxf", convexity = 10);
    }
    module main_split(color) {
        if (render_pcbs) {
            pcb("main_split.dxf", "pcbs/mantis_reversible_split_leds", 1.59, color, color == "white" ? "black" : "white", opacity(color), $fs = $fs/2);
        } else {
            color(color) linear_extrude(height = 1.59, convexity = 10)
                offset(delta = -0.05) translate([-254, 127]) import("main_split.dxf", convexity = 10);
        }
    }
    module plate_main() {
        linear_extrude(height = 2.21, convexity = 10)
            translate([-254, 127]) import("plate_main.dxf", convexity = 10);
    }
    module sound_plate_raised() {
        linear_extrude(height = mid_layer_height - 0.01, convexity = 10)
            translate([-254, 127]) import("sound_plate_raised.dxf", convexity = 10);
    }
    module raised() {
        if (render_pcbs) {
            pcb("raised.dxf", "pcbs/mantis_raised_leds", 1.59, top_color, top_color == "white" ? "black" : "white", opacity(top_color), $fs = $fs/2);
        } else {
            color(top_color) linear_extrude(height = 1.59, convexity = 10)
                offset(delta = -0.05) translate([-254, 127]) import("raised.dxf", convexity = 10);
        }
    }
    module plate_raised() {
        linear_extrude(height = 2.21, convexity = 10)
            translate([-254, 127]) import("plate_raised.dxf", convexity = 10);
    }

    ex1 = $explode;
    ex2 = 2 * ex1;
    ex3 = 3 * ex1;
    ex4 = 4 * ex1;
    ex5 = 5 * ex1;
    ex6 = 6 * ex1;

    // Solid parts first
    translate([-ex1/2, 0, 4.6 + ex2]) main_split(bottom_color1);
    translate([ ex1/2, 0, 4.6 + 1.59 + ex2]) rotate([0, 180, 0])  main_split(bottom_color2);
    translate([0, 0, 8.4 + mid_layer_height + ex5]) raised();

    color("white", alpha = 0.2) union() {
        translate([0, 0, 10.0 + mid_layer_height + ex6]) plate_raised();

        translate([0, 0, 8.4 + ex4]) sound_plate_raised();
        translate([0, 0, 6.2 + ex3]) plate_main();

        translate([0, 0, 1.6 + ex1]) sound_plate_main();

        base();
    }
}

module sound_channels() {
    module base() {
        linear_extrude(height = 4.59, convexity = 10)
            translate([-254, 127]) import("base.dxf", convexity = 10);
    }
    module raised_outline() {
        linear_extrude(height = 3.8 + mid_layer_height, convexity = 10)
            translate([-254, 127]) import("raised_outline.dxf", convexity = 10);
    }
    module sound_plate_main() {
        linear_extrude(height = 3.01, convexity = 10)
            translate([-254, 127]) import("sound_plate_main.dxf", convexity = 10);
    }
    module main_split() {
        linear_extrude(height = 1.61, convexity = 10)
            offset(delta = 0.01) translate([-254, 127]) import("main_split.dxf", convexity = 10);
    }
    module plate_main() {
        linear_extrude(height = 2.21, convexity = 10)
            translate([-254, 127]) import("plate_main.dxf", convexity = 10);
    }
    module sound_plate_raised() {
        linear_extrude(height = mid_layer_height + 0.01, convexity = 10)
            translate([-254, 127]) import("sound_plate_raised.dxf", convexity = 10);
    }
    module raised() {
        linear_extrude(height = 1.61, convexity = 10)
            translate([-254, 127]) import("raised.dxf", convexity = 10);
    }

    color("white", alpha = 0.4) render(convexity = 10) difference() {
        union() {
            translate([0, 0, 1.605]) base();
            translate([0, 0, 6.195]) raised_outline();
        }

        translate([0, 0, 1.6]) sound_plate_main();

        translate([0, 0, 4.6]) main_split();
        translate([0, 0, 4.6]) mirror([1, 0, 0]) main_split();

        translate([0, 0, 6.2]) plate_main();

        translate([0, 0, 8.4]) sound_plate_raised();

        translate([0, 0, 8.4 + mid_layer_height]) raised();
    }
}

cos30 = cos(30);
module half_mantis() {
    hx = 21.5 + $explode/5;
    hy = -hx*cos30;
    dx = 3;
    dy = -dx/cos30;
    raise = 3.8 + mid_layer_height + 3*$explode;
    translate([-4.5*hx-dx/2, -3*hy, 0]) {
        translate([0  *hx, 0*hy   ,     0]) rotate([0, 0,    0]) switch_key($tilt = tilt1, $rise = rise1);
        translate([1  *hx, 0*hy   ,     0]) rotate([0, 0,  -60]) switch_key($tilt = tilt2, $rise = rise2);
        translate([2  *hx, 0*hy   ,     0]) rotate([0, 0,  -60]) switch_key($tilt = tilt2, $rise = rise2);
        translate([3  *hx, 0*hy   ,     0]) rotate([0, 0,  -60]) switch_key($tilt = tilt2, $rise = rise2);
        translate([3.5*hx, 1*hy   , raise]) rotate([0, 0,  -60]) switch_key($tilt = tilt2, $rise = rise2);
        translate([4  *hx, 2*hy   , raise]) rotate([0, 0,  -60]) switch_key($tilt = tilt2, $rise = rise2);
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

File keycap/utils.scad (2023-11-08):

function rotate_x(point, angle) = [
    point.x,
    point.y*cos(angle) - point.z*sin(angle),
    point.z*cos(angle) + point.y*sin(angle)
];
function rotate_x_around(point, angle, origin=[0, 0, 0]) =
    rotate_x(point - origin, angle) + origin;

function rotate_z(point, angle) = [
    point.x*cos(angle) - point.y*sin(angle),
    point.y*cos(angle) + point.x*sin(angle),
    point.z
];

function scale_x(point, factor) = [point.x * factor, point.y, point.z];

// Soft clamping of z coordinates using hyperbola
// z1: z value to start clamping at
// z2: asymptotic maximum z value
// Uses an inverted hyperbolic functon to compress z values
// from [z1, inf) into the range [z1, z2)
function clamp_z_hyper(points, z1, z2) = let (d = z2 - z1)
    [for (p = points)
        [p.x, p.y, p.z < z1 ? p.z :
         z2 - d / (1 + (p.z - z1) / d)]
    ];

// Soft clamping of z coordinates using exponential function
// z1: z value to start clamping at
// z2: asymptotic maximum z value
// Uses an inverted exponential functino to compress z values
// from [z1, inf) into the range [z1, z2)
function clamp_z_exp(points, z1, z2) = let (d = z2 - z1)
    [for (p = points)
        [p.x, p.y, p.z < z1 ? p.z :
         z2 - d * exp((z1 - p.z) / d)]
    ];

function part_sums(seq) = [for (a = 0, i = 0; i <= len(seq);
                                a = a + seq[min(i, len(seq)-1)],
                                i = i + 1) a];

// Faces filling the space between concentric rings of points with
// shrinking numbers of points per ring towards the center
function concentric_faces(n, n_points, offset = 0) = let (
    offsets = part_sums(n_points),
    faces1 = [for (i = [0 : n - 1]) each let (
            o = offsets[i] + offset,
            ni = n_points[i],
            ni_1 = n_points[i + 1],
            ratio = ni_1 / ni
        )
        [for (j = [0 : ni - 1])
            [(j + 1) % ni + o, j + o,
             ni + round((j + 0.5) * ratio) % ni_1 + o]
        ]
    ],
    faces2 = [for (i = [0 : n - 2]) each let (
            o = offsets[i],
            ni = n_points[i]
        )
        [for (i = 0; i < ni; i = i + 1)
            if (faces1[i + o][2] != faces1[(i + 1) % ni + o][2])
                [faces1[i + o][2], faces1[(i + 1) % ni + o][2],
                 faces1[i + o][0]]
        ]
    ]) concat(faces1, faces2);

// Half sphere with optimized number of faces for faster minkowski sums
module half_sphere(r) {
    n = max(2, ceil(90 / $fa));
    da = 90 / n;
    n_points = concat([for (a = [0 : da : 89.9])
            max(3, ceil(cos(a) * 360 / $fa))
        ], [1]);
    points = [for (i = [0 : n]) each let (a = da * i, q = r * cos(a))
        [for (j = [0 : n_points[i] - 1]) let (b = 360 / n_points[i] * j)
            [q * sin(b), q * cos(b), -r * sin(a)]/*[i, j, a, b]*/
        ]
    ];

    face_top = [for (i = [0 : n_points[0] - 1]) i];
    faces = concat([face_top], concentric_faces(n, n_points));
        
    polyhedron(points, faces);
}

half_sphere(3, $fa = 360 / 16);

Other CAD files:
keycap/keycap.stl
keycap/raised_outline.dxf
keycap/raised.dxf
keycap/deprecated/keycap-v2-28.stl
keycap/deprecated/keycap.stl
keycap/keycap-v2-28.stl
keycap/pcbs/mantis_raised_leds-B_Mask.dxf
keycap/pcbs/mantis_raised_leds-B_Silkscreen.dxf
keycap/pcbs/mantis_raised_leds-F_Mask.dxf
keycap/pcbs/mantis_raised_leds-F_Silkscreen.dxf
keycap/pcbs/mantis_reversible_split_leds-B_Mask.dxf
keycap/pcbs/mantis_reversible_split_leds-B_Silkscreen.dxf
keycap/pcbs/mantis_reversible_split_leds-F_Mask.dxf
keycap/pcbs/mantis_reversible_split_leds-F_Silkscreen.dxf
plates/v0.3/base.dxf
plates/v0.3/mantis-1x-3mm-all.dxf
plates/v0.3/mantis-2x-3mm-all.dxf
plates/v0.3/plate_raised.dxf
plates/v0.3/sound_plate_raised.dxf

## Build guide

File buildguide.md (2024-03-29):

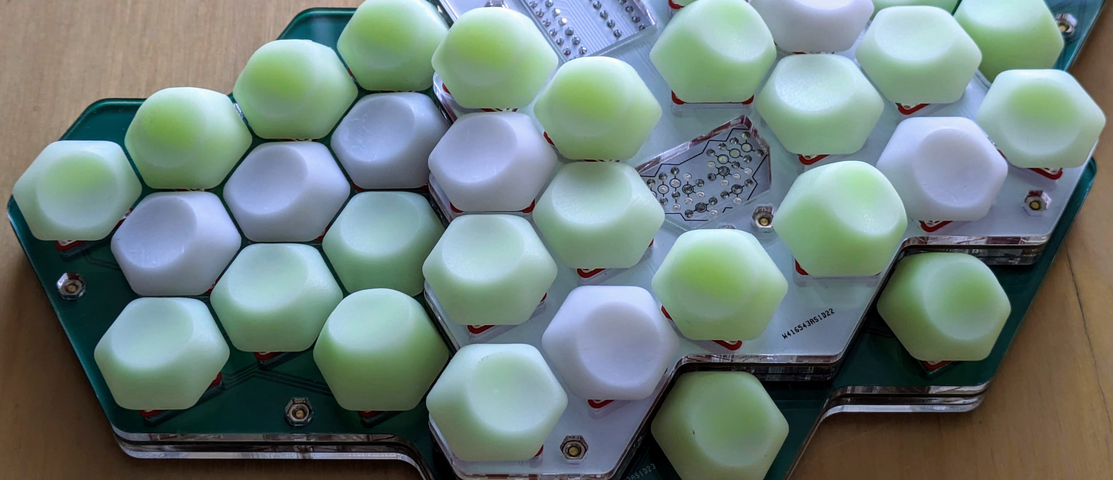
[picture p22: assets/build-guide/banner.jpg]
Banner


# Mantis v0.3.3 Build Guide

## Pre-requisites

Before you start, make sure you have all the parts and tools you will need to complete the build, and that you have a working QMK build environment.

### Parts

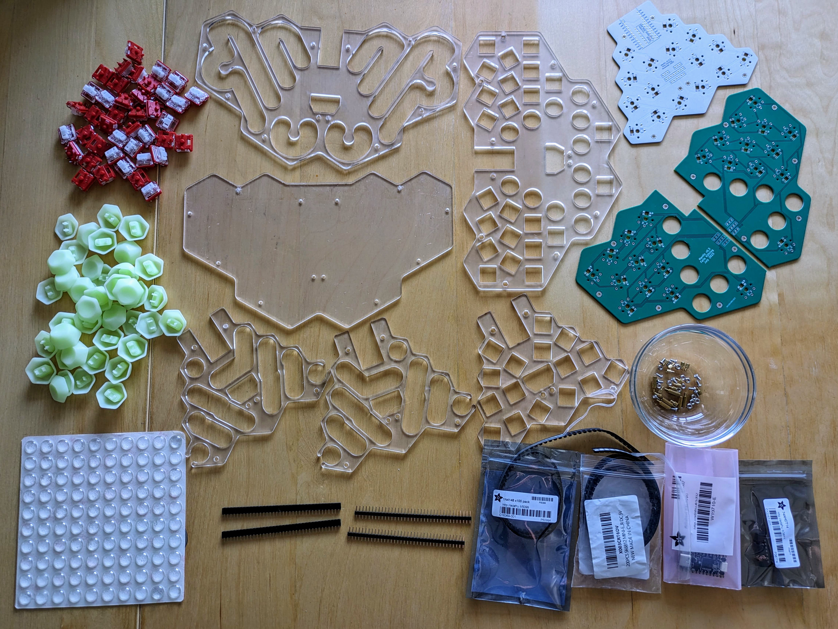
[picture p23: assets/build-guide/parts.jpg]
Parts
>

These are all the parts needed to build one Mantis keyboard.

- 1x [upper PCB](https://github.com/fxkuehl/mantis/raw/main/pcb/gerber/mantis-v0.3.3-top.zip)
- 2x [lower PCBs](https://github.com/fxkuehl/mantis/raw/main/pcb/gerber/mantis-v0.3-bottom.zip)
- 40x [custom 3D printed keycaps](https://github.com/fxkuehl/mantis/tree/main/keycap) (FK Keycaps Hex keys also work but not ideal)
- [Case plates](https://github.com/fxkuehl/mantis/tree/main/plates/v0.3.3) (3mm. If different thickness is used, you may need to use different headers and standoffs)
    - 1x base plate
    - 1x lower sound plate
    - 1x lower switch plate
    - 2x upper sound plate
    - 1x upper switch plate
- 1x ProMicro or pin-compatible controller (I used Adafruit's KB2040 in my latest builds)
- 1x Logic Level Inverter / Level Shifter (74AHCT14, only need for RGB with 3.3V controllers)
- 1x reset switch (optional, only useful with ProMicro)
- 40x SMD diodes (SOD-123)
- Up to 40x RBG LEDs (SK6812 MINI-E)
- 40x Choc v1 switches
- Headers: (I used 5mm short headers from Adafruit in my latest builds. 8mm headers work if you mount the male headers from the bottom of the lower PCBs, pushing the pins all the way through)
    - 2x 12-pin headers for controllers
    - 2x 3-pin, 1x 8-pin and 1x 6-pin headers for connecting the upper and lower PCBs
- 12x 3mm knurled M2 male-female standoffs
- 6x 9mm knurled metal M2 male-female standoffs (don't use plastic standoffs, they serve as GND connection between the PCBs)
- 12x M2 screws
- 12x M2 hex nuts
- Adhesive rubber feet

### Tools

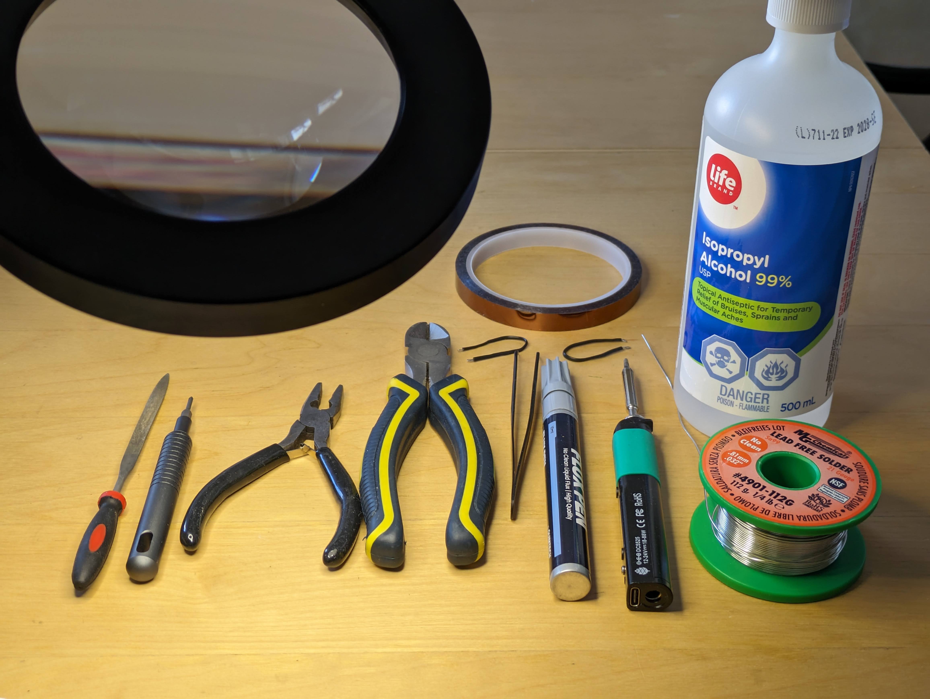
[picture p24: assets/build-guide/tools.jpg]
Tools
>

You will need the following tools and materials:

- Soldering iron (ideally digitally temperature controlled)
- Solder (I prefer lead-free solder, but leaded solder is easier to work with especially for soldering temperature-sensitive RGB LEDs)
- Flux (helps with soldering RGB LEDs)
- Rubbing alcohol (for cleaning up flux residue)
- Tweezers (for placing SMD diodes and LEDs)
- Pliers (for pulling header pins and tightening standoffs)
- Diagonal cutter (for cutting headers)
- Adhesive tape (for securing headers while soldering)
- Small file or sand paper (for adjusting standoffs)
- Small screw driver (for M2 screws in the bottom of the case)
- Paper clips (for testing the key matrix before installing the switches)

I would also recommend a magnifying glass and good lighting for placing and soldering the SMD components. I use a magnifying lamp.

## Build Process Overview

This is a breakdown of the build process. The rest of this build guide will explain each step in more detail.

1. Build and flash the firmware on the controller
    1. Get the source code
    2. Compile the firmware for your type of controller
    3. Flash the firmware to the controller
    4. Verify the firmware with Vial
2. Solder the top PCB
    1. Solder level shifter (if using 3.3V controller and RGB LEDs)
    2. Close direct jumper (if using 5V controller and RGB LEDs)
    3. Solder controller headers to PCB
    4. Socket the controller
    5. Solder diodes
    6. Solder RGB LEDs
    7. Test LEDs and diodes
3. Solder Bottom PCBs
    1. Solder diodes
    2. Solder RGB LEDs
    3. Cut and solder male headers on bottom PCBs
4. Preliminary assembly and testing
    1. Cut female headers for top PCB
    2. Align and assemble top and bottom PCBs with loose headers on top PCB
    3. Solder female headers on top PCB
    4. Test LEDs and diodes on bottom PCBs
    5. Disassemble top and bottom PCBs again
5. Switch installation and final assembly and testing
    1. Align top switch plate with top PCB and install+solder switches on top PCB
    2. Test switches on top PCB
    3. Align bottom switch plate with bottom PCBs and install+solder switches on bottom PCBs
    4. Adjust standoffs
    5. Install 9mm standoffs on top PCB assembly and align with top sound plates
    6. Align and connect bottom PCB assembly, install 3mm standoffs
    7. Test switches on bottom PCBs
    8. Align bottom switch plate and base plate, close the case
    9. Add bumpers
    10. Install key caps

## 1. Build and flash the firmware on the controller

First we'll prepare the controller with the correct firmware. This will allow you to test your work as you go along, while parts are accessible for correcting mistakes.

### 1.1 Get the source code

I will assume that you already have a QMK build environment set up. I use a Linux PC to build and flash firmware. Refer to the [QMK documentation](https://docs.qmk.fm/#/newbs_getting_started) if you haven't built QMK before.

We will add a new remote (my fork of QMK) to your local QMK git repository, create a new local branch tracking my mantis-vial-v0.3 branch and checkout that branch. In my example I will assume that you have QMK checked out in `~/qmk_firmware`.

Before you start, make sure your ```git status``` is clean.

```
$ cd ~/qmk_firmware
$ git remote add fxkuehl https://github.com/fxkuehl/qmk_firmware
$ git fetch fxkuehl
$ git branch -t mantis-vial-v0.3 fxkuehl/mantis-vial-v0.3
$ git checkout mantis-vial-v0.3
```

### 1.2 Compile the firmware for your type of controller

Mantis should work with any controller that is pin-compatible with ProMicro and supported by QMK. You can see a complete list of supported converters for drop-in replacement controllers [in the QMK documentation](https://docs.qmk.fm/#/feature_converters). If you're using a ProMicro, you can build the firmware with

```
$ qmk compile -kb mantis -km vial
```

If you are using a drop-in replacement, choose the correct converter. In my example, I'm using a kb2040 from Adafruit:

```
$ qmk compile -kb mantis -km vial -e CONVERT_TO=kb2040
```

### 1.3 Flash the firmware to your controller

Flashing the firmware requires putting your controller into boot-loader mode. Please refer to the documentation for your controller for details. The following command should wait for your controller to enter that mode and then flash the firmware. Use the same `-e CONVERT_TO=...` option as in the `qmk compile` command above, e.g.:

```
$ qmk flash -kb mantis -km vial -e CONVERT_TO=kb2040
```

### 1.4 Verify the firmware with Vial

If you don't have Vial yet, [get.vial.today](https://get.vial.today/). You can use either the web version, if your browser is supported, or download the correct package for your OS. At this point, we only want to make sure that Vial detects your controller as a "Felix Kuehling Mantis" keyboard. You should see the layout with the default keymap.

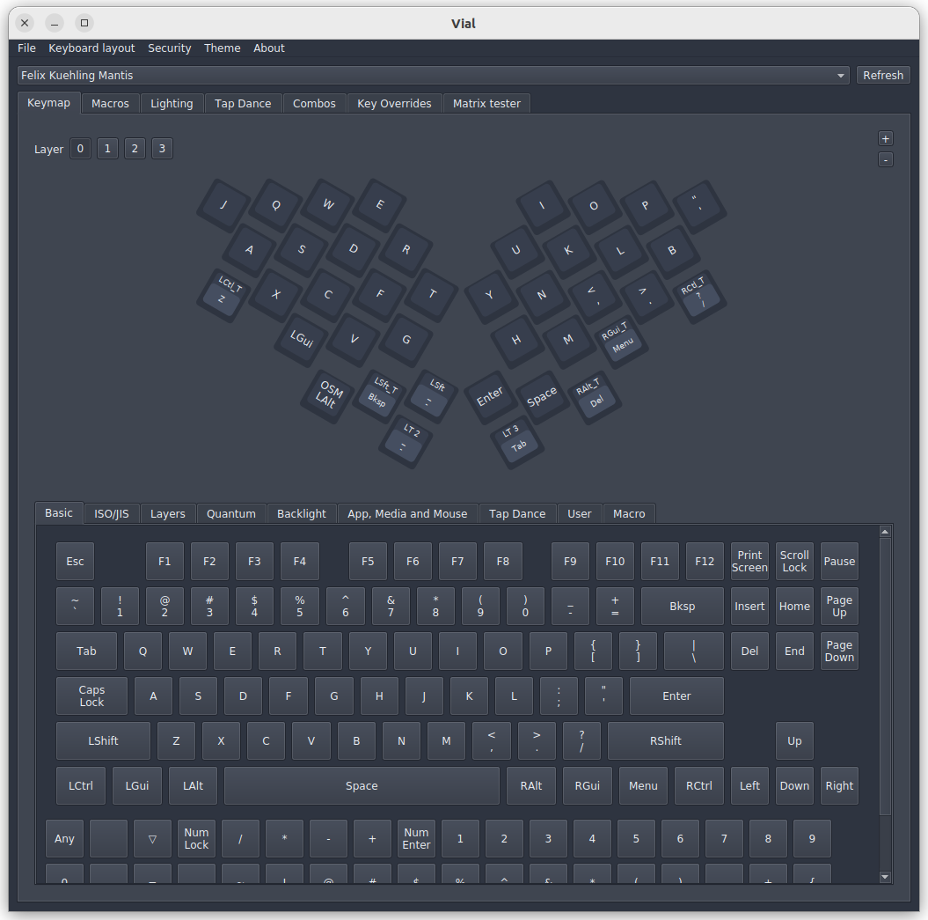
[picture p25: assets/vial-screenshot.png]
Vial screenshot
>

## 2. Solder the top PCB

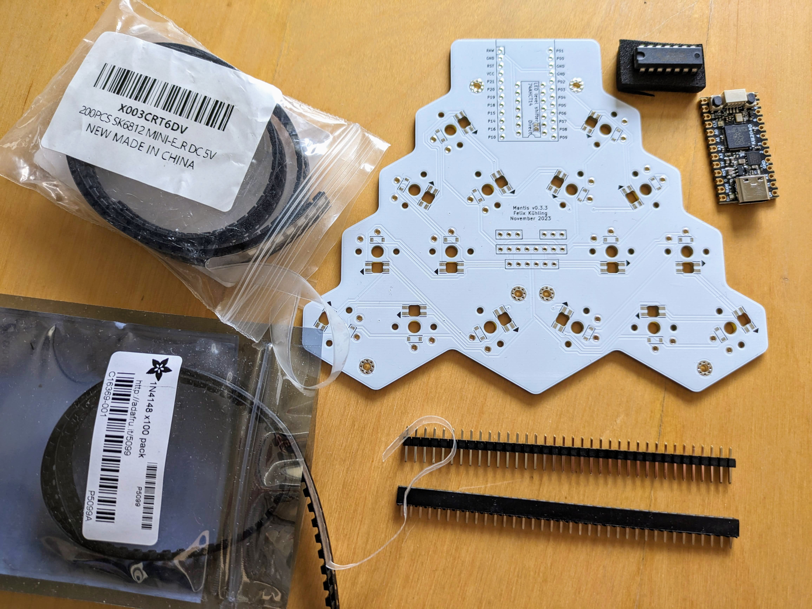
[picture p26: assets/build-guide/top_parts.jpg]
Top PCB and parts
>

In this part of the build we will solder most of the components on the top PCB, including the controller, diodes and RGB LEDs. We're not going to install the switches yet, though. Before we move on to the bottom PCBs, we can test that all the LEDs light up and that the diodes are installed correctly and the controller can detect all 16 keys on the top PCB.

Before starting, identify the bottom side of the top PCB (shown in the picture above), which is where all the components will be mounted. You should see the pads for the diodes and RGB LEDs, as well as silk-screen legends for the controller and level shifter.

### 2.1 Solder level shifter (if using 3.3V controller and RGB LEDs)

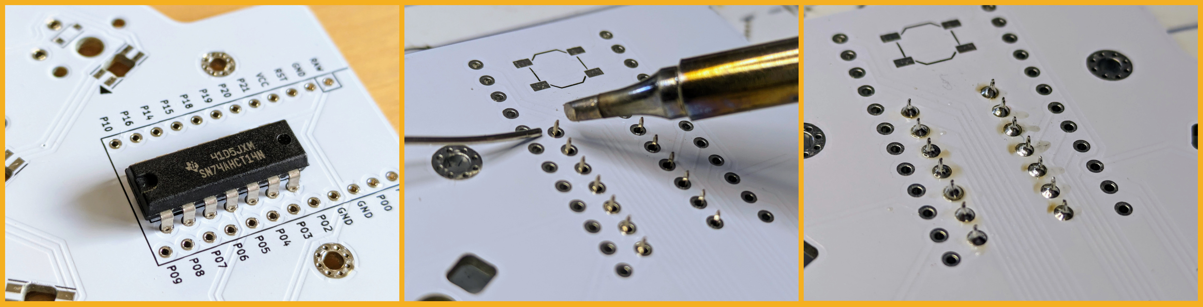
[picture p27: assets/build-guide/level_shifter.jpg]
Level shifter


If you're using a controller with 3.3V logic and want to use RGB LEDs, you need to install the voltage level shifter to adapt the output voltage of the controller for the DIN pin of the first RGB LED. Insert the pins of the 74AHCT14 from the bottom of the PCB in the correct orientation with the notch as indicated on the silk-screen. Then solder the pins from the top of the PCB.

### 2.2 Close direct jumper (if using 5V controller and RGB LEDs)

If you just installed the level-shifter skip this step. If you are using a 5V (original ProMicro) controller and want to use RGB LEDs, you don't need a level-shifter. In that case just solder the jumper with the label "Direct" on the bottom of the PCB. This connects the controller pin directly to the first DIN pin of the first RGB LED.

### 2.3 Solder controller headers to PCB

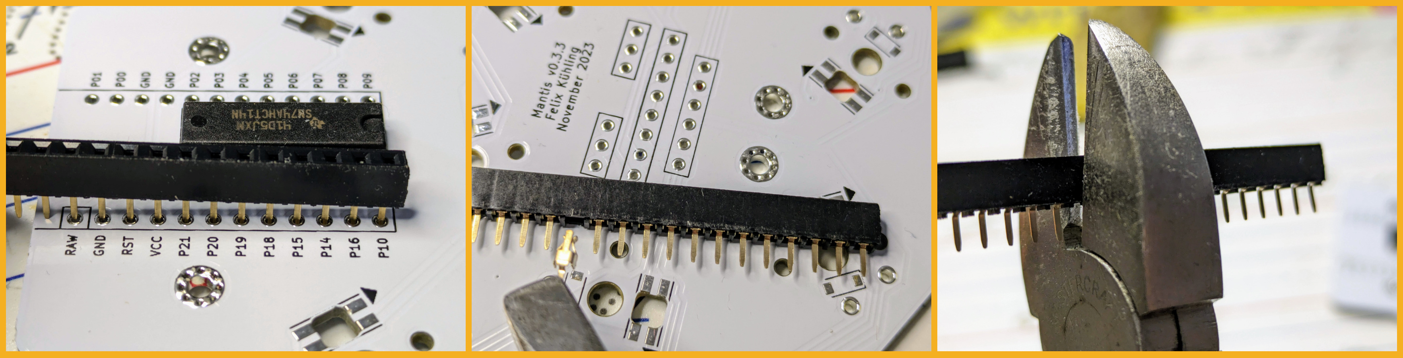
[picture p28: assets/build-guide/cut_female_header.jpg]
Cutting headers to size


The controller will be mounted using the same type of headers used to connect the top and bottom PCBs later. Insert two rows of 12-pin female headers on the bottom of the top PCB. If you need to cut 40-pin headers to the correct size, see this [tutorial](https://learn.adafruit.com/how-to-solder-headers/female-headers#cutting-female-headers-to-size-3076508).

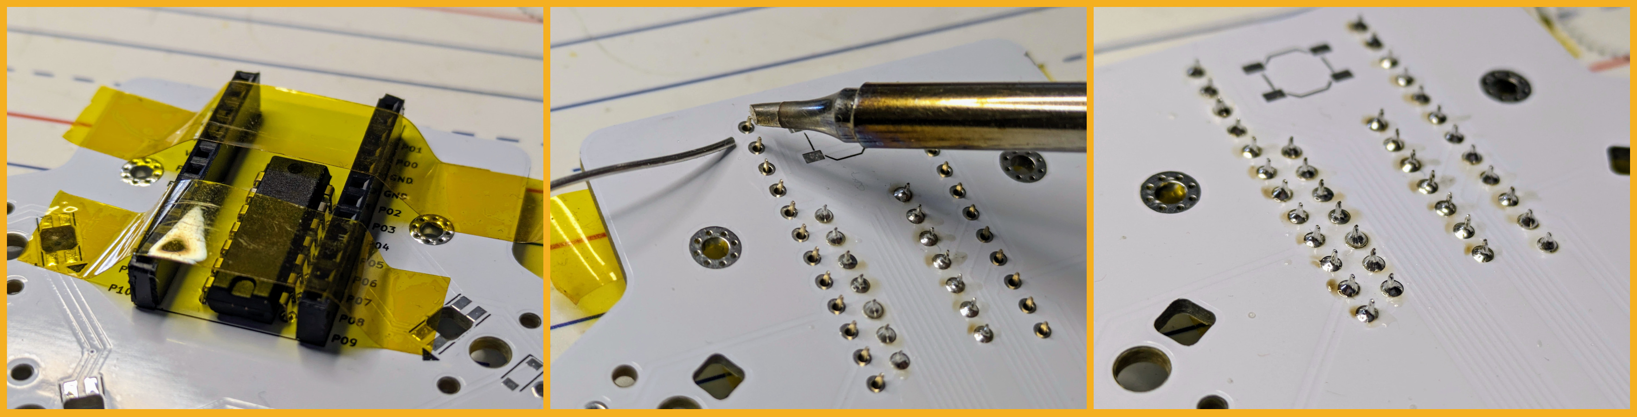
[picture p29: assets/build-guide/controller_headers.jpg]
Soldering controller headers


Secure them with tape. Make sure they're parallel and straight before you solder them. Turn the PCB over and solder the pins from the top. Then remove the tape.

### 2.4 Socket the controller

> _The following instructions assume that you're using short headers (5mm) available from Adafruit. If  you're using normal 8mm headers, there is a trick to make them work. See the section about 8mm headers in the Appendix._

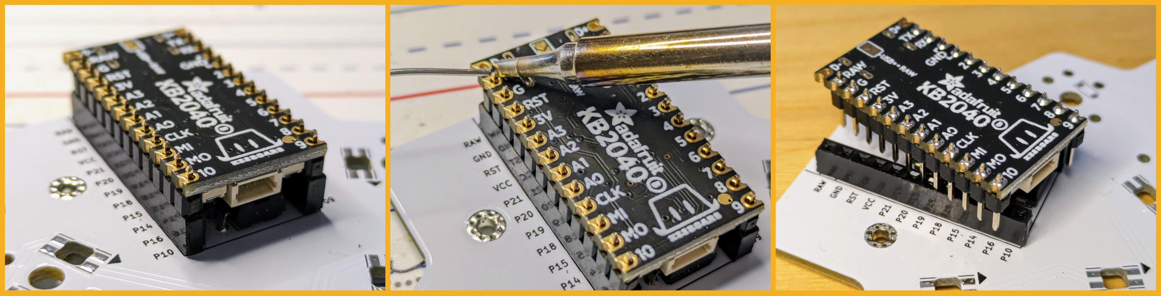
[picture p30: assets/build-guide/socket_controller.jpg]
Socket the controller


We'll solder the corresponding male headers to the controller. Insert the long side of the male headers into the female headers already mounted on the PCB. Place the controller on the male headers so that the short side sticks through the plated through-holes on the controller with the components of the controller facing the Mantis PCB and the USB port pointing to the edge of the PCB. If your controller has 13 through-holes on each side, ignore the ones closest to the USB port (labelled D+ and D-).

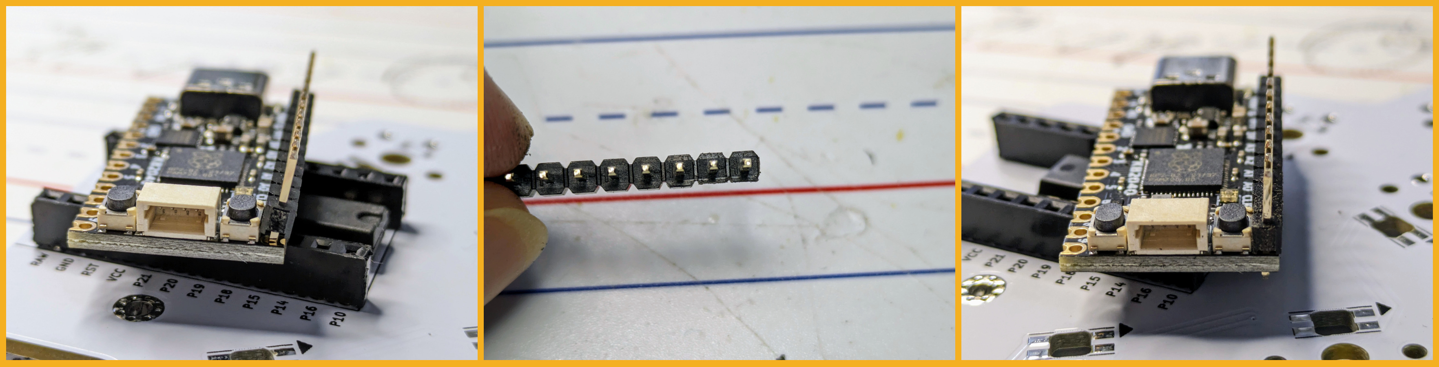
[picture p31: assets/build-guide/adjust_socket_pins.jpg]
Adjust socket pins


If some components (e.g. reset switches) on the controller are too close to the header, you may need to file down the plastic part of the header to make it fit. Once you have a good fit, solder the pins to the controller.

Unplug the controller carefully from the socket to avoid bending any pins and keep it in a safe place until later.

### 2.5 Solder diodes

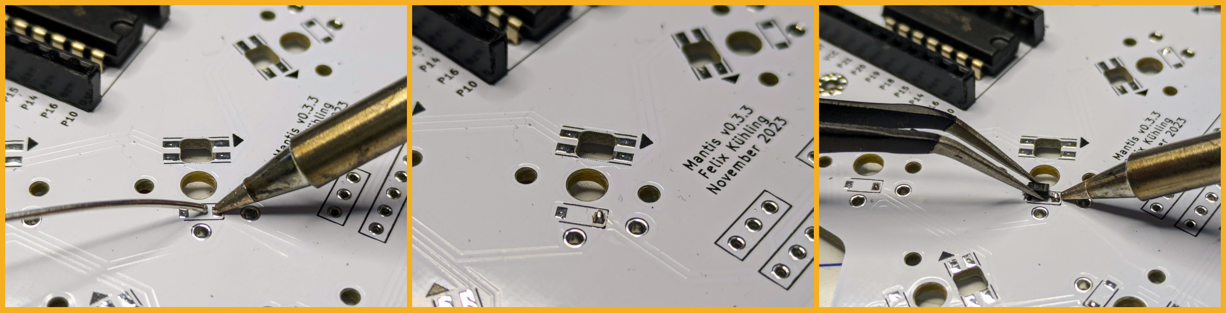
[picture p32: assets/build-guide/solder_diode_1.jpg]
Solder diode part 1


First use the soldering iron to add a small blob of solder to one pad of each diode. To make it easier to install the diodes in the correct orientation, do this on the same side for each diode. The silkscreen markings may be a bit hard to read if the silk screen isn't perfectly aligned with the solder mask (I'll use more obvious silkscreen legend on the next PCB revision). On the top PCB the bar on the diode will face towards the outer switch pin. The silkscreen outline should be closed on that side. Add the solder blob to the pad on that side for reference.

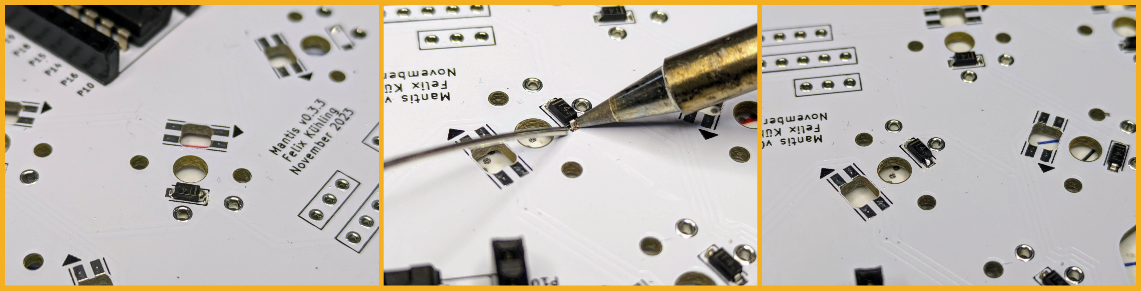
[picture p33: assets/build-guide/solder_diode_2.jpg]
Solder diode part 2


Now carefully place the diodes, one at a time, using tweezers. Make sure the bar on the diode is facing toward the pad where you just placed the solder blob. Melt the solder blob with the soldering iron and push the diode into place. Then remove the iron to let the solder solidify. The diode should be firmly in place now. If you need to reposition it, melt the solder again and move the diode using the tweezers.

Once you've placed all the diodes, you can revisit each diode and solder the other pin to its pad.

### 2.6 Solder RGB LEDs

LEDs add some bling to your keyboard and can be useful indicators. However, this is the trickiest part of the build, in my experience. If you overheat the LEDs, some colors may not work any more or they may be broken altogether. Also, because of the way the LEDs are chained, one broken link (bad solder joint) in the chain will affect all the downstream LEDs. The keyboard works without LEDs, so you can skip this step to save yourself time and hassle.

>_The way the LEDs are chained, you also have a few options to build the keyboard with fewer LEDs:_
>
> 1. _Only the top 6 LEDs on the top PCB, to use as indicators_
> 2. _Only the 16 LEDs on the top PCB_
> 3. _All 40 LEDs_

Soldering the LEDs is easier with leaded solder, which melts at a lower temperature. I ruined two PCBs when I tried to solder LEDs with a cheap soldering iron and lead-free solder. For best results, prepare the pads on the PCB with flux and use a decent soldering iron with good temperature control. Choose a tip that is large enough to ensure good heat transfer but small enough so you can heat one pad at a time.

Take your time with this step and take breaks if you need to. If it's not working, make sure the solder tip is clean and free of oxidation, and that the temperature is right.

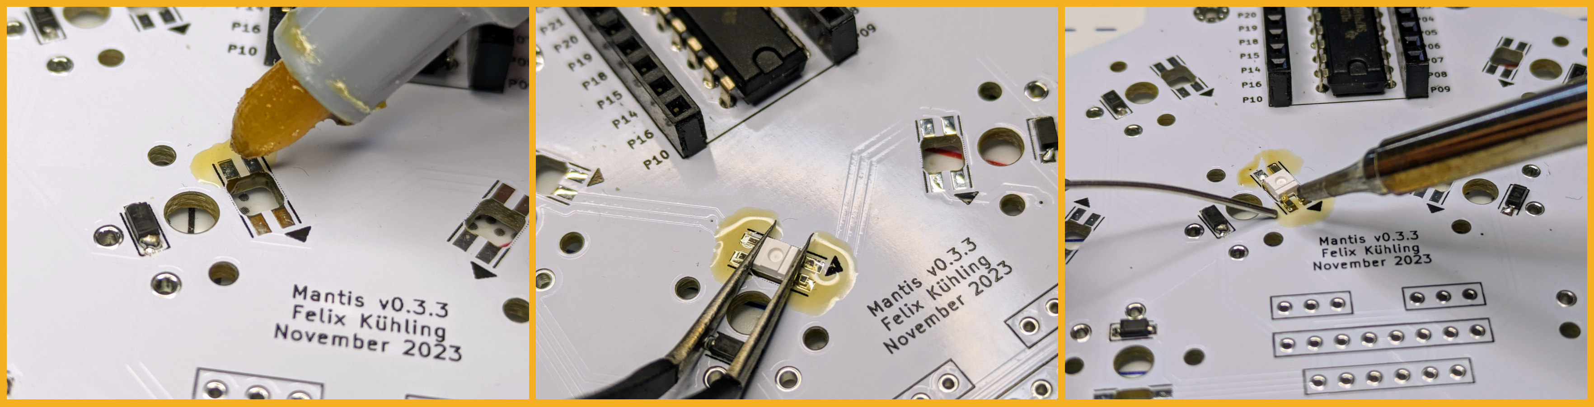
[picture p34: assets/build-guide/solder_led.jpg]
Solder LEDs


When placing the LEDs, make sure the orientation is correct. The light-emitting side should go into the cut-out in the PCB. One of the pins is missing a corner, which should align with the arrow on the silkscreen. Place the LED into the cut-out and push it down until the pins are flush with the pads.

Melt a small amount of solder on the tip of your iron and use it to tack one pin to keep the LED in place while soldering the remaining pins. Then heat one pin and pad at a time and solder it properly. Melt the solder on the pad, not on the solder tip. It doesn't take a lot of solder to make a good connection if you're using flux to make sure the solder goes in the right place (i.e. between the pin and the pad). Rotate the PCB to help you reach each pin without melting the LED housing.

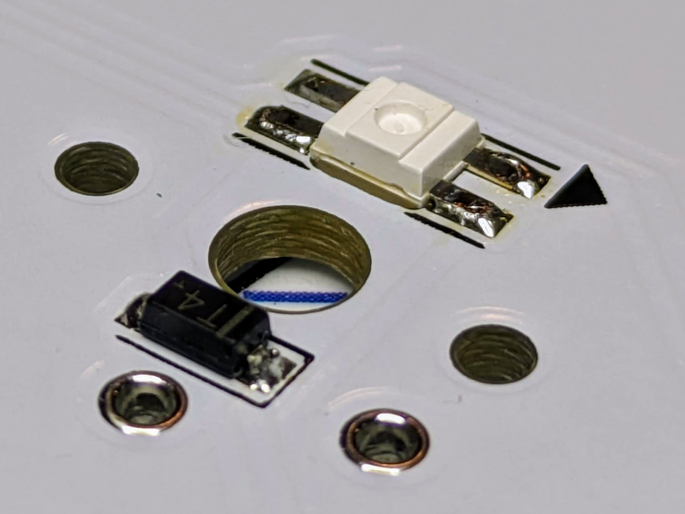
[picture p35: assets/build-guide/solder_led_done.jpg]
Good LED
>

I like to place a few LEDs with the same orientation on the PCB at once. That way I don't need to turn the PCB as many times when soldering.

### 2.7 Test LEDs and diodes

This is a good time to plug the controller into the top PCB and connect it to your computer to test your work. You should see all the LEDs light up. If some of them are not working, check all the pins on the first LED in the chain that's off, and check the DOUT pin on the last working LED. If necessary, unplug the USB and reflow the solder on any LED pins that need it. Then try again. Repeat this until all the LEDs are lit.

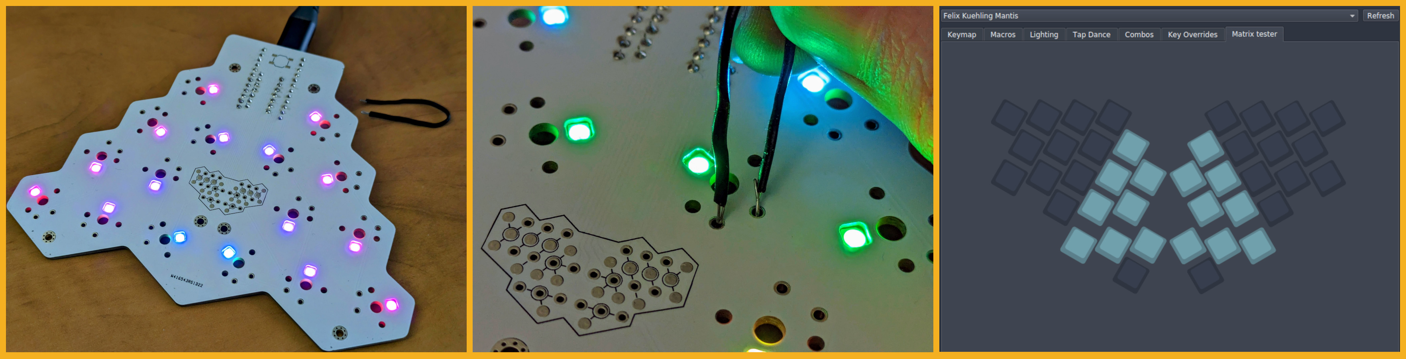
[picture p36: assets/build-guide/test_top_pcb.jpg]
Test


You can test the diodes by bridging the two pads of each switch with a paper clip or short piece of stripped wire. You can use the matrix tester tab in Vial to check that all the keys are working. To unlock the matrix tester, you need to bridge two keys at once (use two paper clips or short wires). Make sure you look at the PCB from the top to hit the right keys.

If you cannot get the matrix tester unlocked, you could also set the backlight mode to one of the reactive modes in the Lighting tab in Vial. Then watch the LEDs respond every time you activate a key successfully. The last option is to just use a text editor. Keep in mind that some keys are mod-taps or modifiers and may not give you an obvious response in the text editor.

If an individual key is not working, check that the diode is soldered on both ends and installed in the right direction. If a whole row or column is not working, check the corresponding controller pins.

## 3. Solder Bottom PCBs

Now we'll move on to the bottom PCBs. These PCBs are reversible. We'll build one left and one right side by installing components on opposite sides. The switch plate will be flush with the PCBs, so all the components go on the respective bottom side of the PCB.

### 3.1 Solder diodes

Because the bottom PCBs are reversible, you cannot use the switch pins to infer the diode directions. Orient the bar on the diode with the closed side of the diode outline on the silkscreen. When soldering the second PCB, pay attention that you're using the opposite side. You don't want to end up with two left halves or two right halves.

### 3.2 Solder RGB LEDs

This works the same as on the top PCB. Make sure you solder the LEDs on the same side as the diodes. Use flux, make sure your soldering iron is clean and at the right temperature. You got this!

### 3.3 Cut and solder male headers on bottom PCBs

> _The following instructions assume that you're using short headers (5mm) available from Adafruit. If  you're using normal 8mm headers, there is a trick to make them work. See the section about 8mm headers in the Appendix._

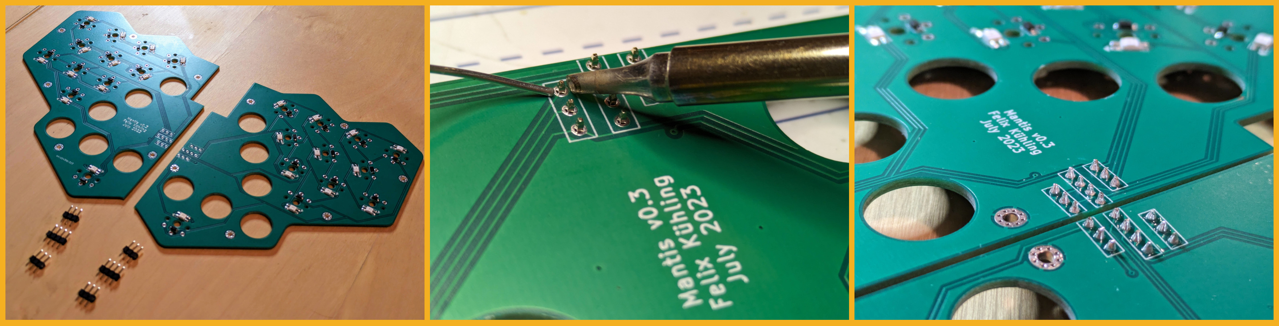
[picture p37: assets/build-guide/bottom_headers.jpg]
Solder bottom headers


Each of the bottom PCBs uses three male headers to connect to the top PCB: 2x 3-pin and 1x 4-pin. Cut the headers to the right size and insert them from the top of each PCB (the opposite side of where you installed the diodes and LEDs). The plated through holes are very tight (for some reason that's how the header footprints came out in KiCad). If you need force, push on the pins, not on the plastic piece. Be careful to push the pins in straight to avoid bending them.

On the positive side, the tight holes should ensure that the pins will be straight and stay in place while soldering. Solder from the bottom.

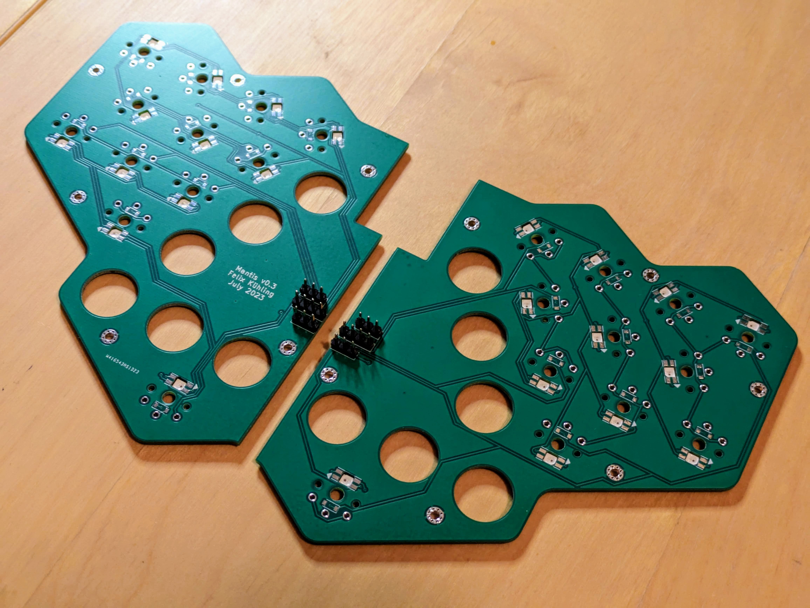
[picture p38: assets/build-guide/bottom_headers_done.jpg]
Bottom headers done
>

## 4. Preliminary assembly and testing

In this step we will partially assemble the keyboard in order to install the female headers on the top PCB and test the LEDs and diodes on the bottom PCB.

### 4.1 Cut female headers for the top PCB

You will need 2x 3-pin, 1x 6-pin and 1x 8-pin female headers.

### 4.2 Align and assemble top and bottom PCBs with loose headers on top PCB

Fasten the 9mm standoffs to the six mounting holes in the top PCB with hex nuts. The standoffs go on the bottom side. Place the top PCB bottom-side-up on your work surface. The controller should be in the socket to make sure everything will fit properly.

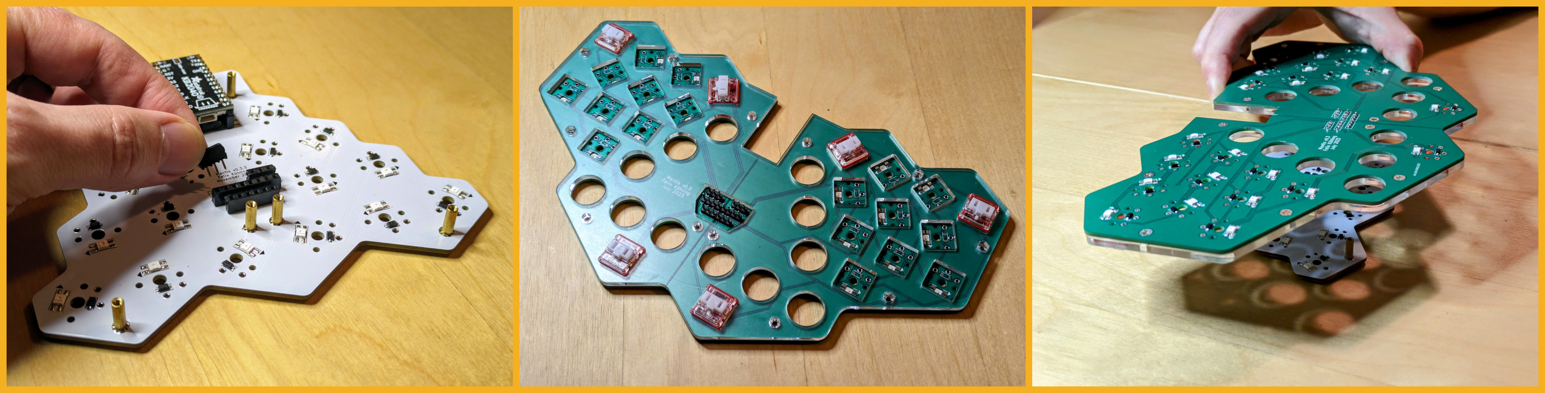
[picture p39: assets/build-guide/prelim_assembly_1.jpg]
Top and bottom assembly


Line up the two bottom PCBs with the switch plate and insert a few switches to keep everything in place. Don't solder the switches yet. Friction should be enough to keep things in place for now. The header pins should stick up through the cutout in the middle of the switch plate. The inner edges of the two bottom PCBs should be completely flush with each other. If necessary, file down any rough edges of the male headers.

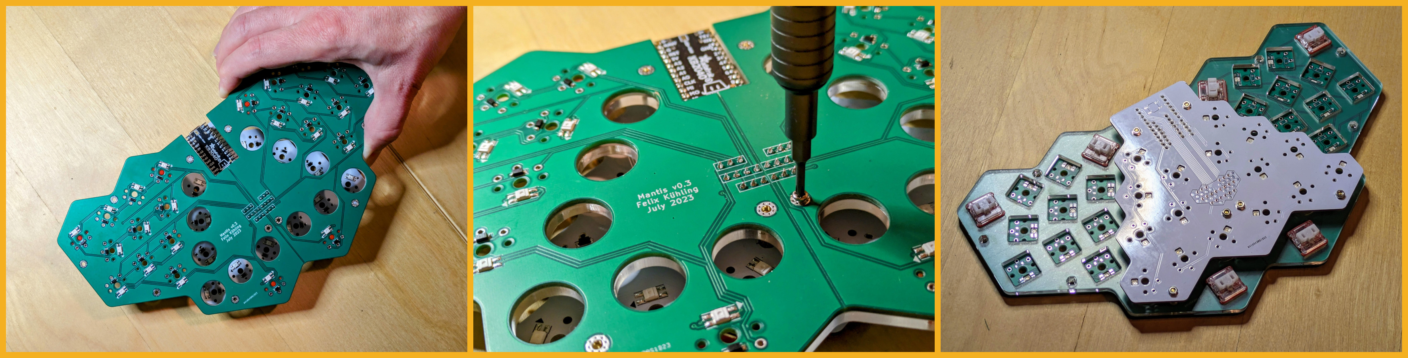
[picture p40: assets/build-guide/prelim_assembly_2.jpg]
Whole keyboard assembly


Loosely insert the female headers into the footprints on the top PCB. Turn over the loose bottom PCB assembly and carefully lower it on the top PCB. Make sure the cutout for the controller lines up correctly, that all the pins of the male headers are correctly inserted into the corresponding female headers and that the standoffs line up with the mounting holes the bottom PCB. Fasten the bottom PCBs to the standoffs with M2 screws. Make sure the two bottom PCBs are properly aligned and flush before you tighten the screws all the way.

### 4.3 Solder female headers on top PCB

Turn the whole assembly over. Make sure that the female headers are still in place and that their pins are sticking evenly through the top PCB. If something is not looking right, disassemble the keyboard and redo the previous step.

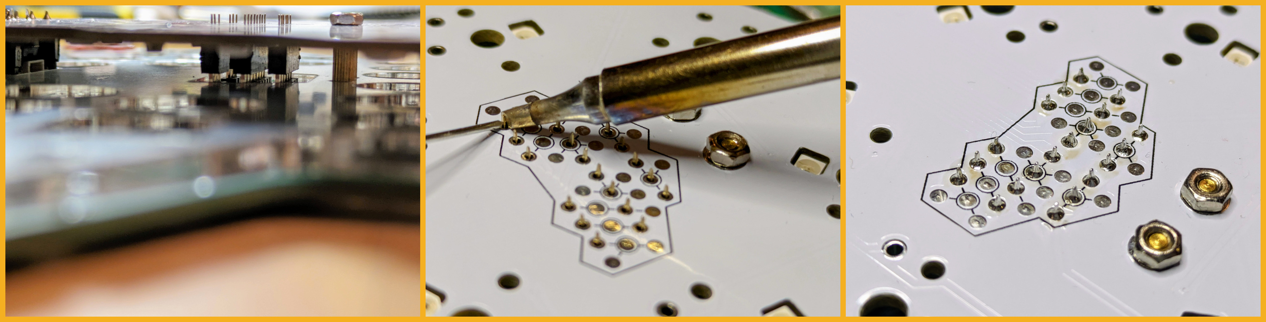
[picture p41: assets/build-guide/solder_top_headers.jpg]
Solder headers to top PCB


Solder the female headers from the top of the top PCB.

### 4.4 Test LEDs and diodes on bottom PCBs

Now, with the keyboard assembled you can plug in the USB cable. You should see the LEDs on the top and bottom PCBs light up. If the bottom LEDs are flickering, you probably don't have a good ground connection. Ground is connected through the standoffs, so make sure the standoffs are in place and properly fastened.

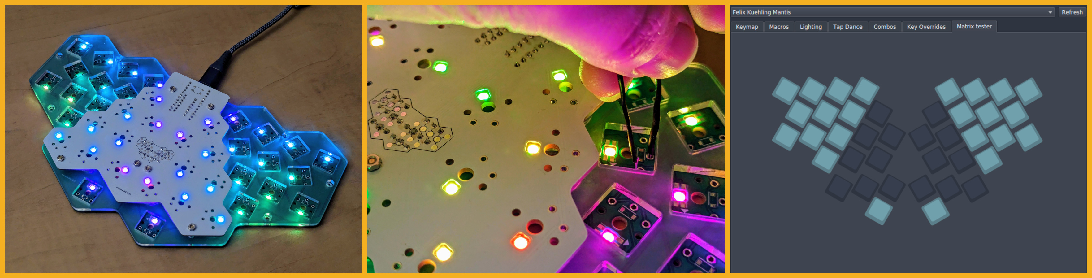
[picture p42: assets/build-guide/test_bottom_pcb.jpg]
Test bottom PCB


Use the same procedure for diagnosing and fixing LEDs as on the top PCB. Use the matrix tester in Vial or a reactive LED mode to make sure all the keys are recognized. On the reversible switch footprint, bridge the middle pad and one of the outer ones. If individual keys are not responding, check the diode direction and connections. If whole rows or columns are not working, check the controller and header pins.

### 4.5 Disassemble top and bottom PCBs again

We need to disassemble the keyboard again before installing the switches and final assembly. This is also a good time to cleanup any leftover flux from all the PCBs, especially if you're using clear acrylic case plates.

## 5. Switch installation and final assembly and testing

We've made it through the most difficult and tedious parts of the build now. We're ready for the final assembly of the keyboard, including the case, switches and keycaps.

### 5.1 Align top switch plate with top PCB and install+solder switches on top PCB

In this step we install the top switch plate and switches on the top PCB. After this step you won't be able to remove the top switch plate without desoldering the switches. If the switch plate is still covered by protective plastic or paper films, remove them now. If you're using clear acrylic plates, avoid leaving finger prints especially on the bottom side that won't be accessible once the switches are installed.

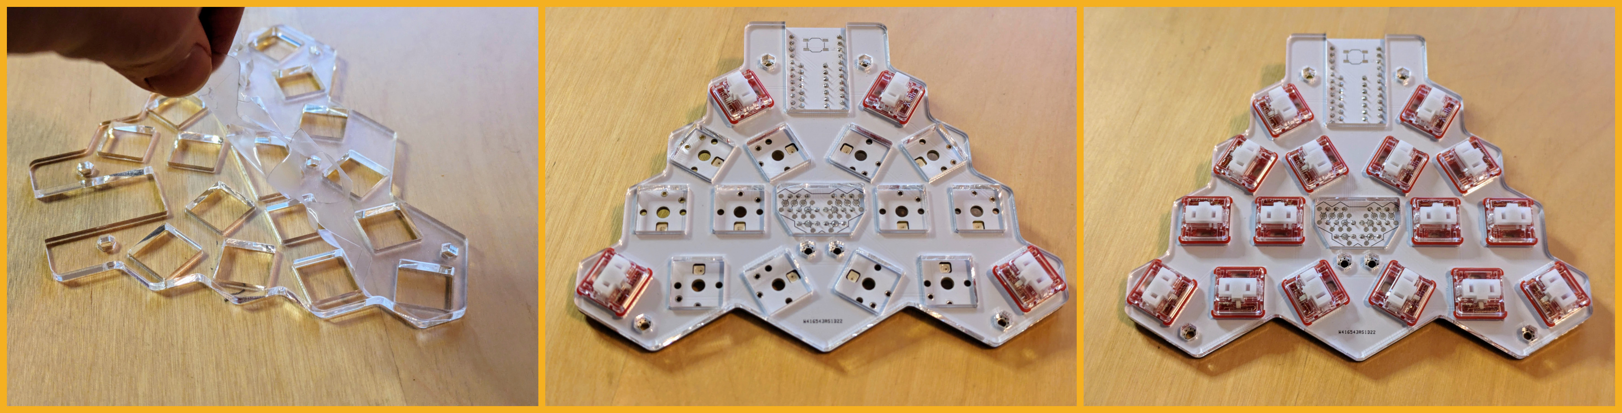
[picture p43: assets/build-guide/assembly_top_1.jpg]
Top assembly


The edges of laser cut plates can be sharp. One side may be sharper than the other. Place the sharp edges down towards the PCB.

Insert the switches at the corners first. Make sure the the pins are straight and line up with the through-holes before you push the switches down. Once the switch plate and PCB are aligned and held in place by the corner switches, insert the remaining switches.

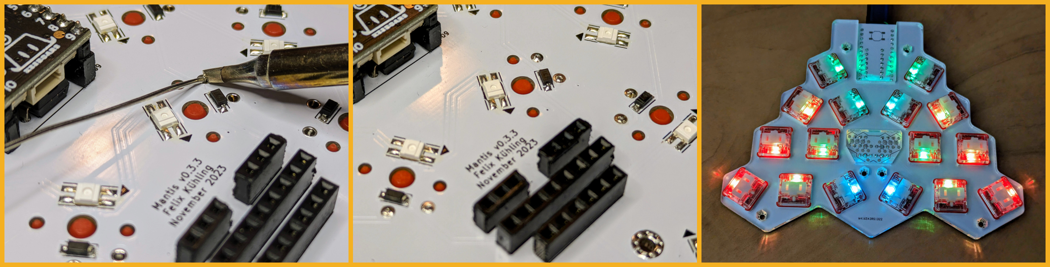
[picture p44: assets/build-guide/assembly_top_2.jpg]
Top assembly


With all the switches firmly in place, turn the assembly over. Make sure the switch pins protrude through the holes. They won't protrude much because the 3mm switch plate is a bit thicker than the bottom switch housing, but they should protrude enough to make a solder joint. Then solder the switch pins from the bottom. Heat both the pad and the pin and make sure the solder flows into the hole.

### 5.2 Test switches on the top PCB

This is a good time to test the switches you just installed. If any switches aren't working, check the solder joints and reflow the solder if needed.

### 5.3 Align bottom switch plate with bottom PCBs and install+solder switches on bottom PCBs

You already did a partial assembly of the bottom PCBs and the switch plate earlier. If the plate still had protective film on it, remove it now. Align the plate with the two bottom PCBs and insert the switches starting with the corners. The header pins should stick up through the cut-out in the center of the switch plate. If the edges of the plate are sharper on one side, turn the sharper edges down towards the PCBs. Make sure the switch pins are straight before inserting them.

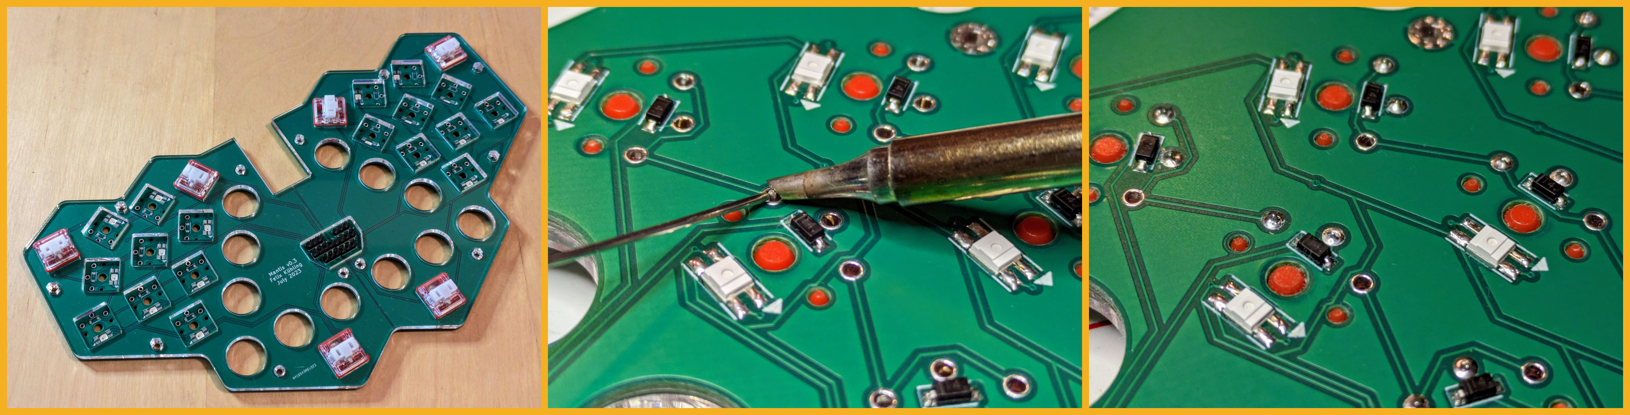
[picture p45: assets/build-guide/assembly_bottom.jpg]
Bottom assembly


Once all the switches are in place check the alignment of the PCBs and the switch plate. The PCBs should be flush in the middle and all the edges aligned with the switch plate. Check that all the switches are properly inserted, then solder the switch pins from the bottom.

If you're using clear acrylic case plates and you want a clean look, you may want to clean up any flux residue from soldering the switches.

### 5.4 Adjust standoffs

The standoffs may be slightly longer than the plates are thick by a fraction of a millimeter. In my experience, acrylic plate thickness is very accurate. Wooden plates can be off by more than 0.1mm. Over three plates that error can add up enough to be noticeable.

In order to get a case that closes firmly without any rattling plates, it may be necessary to file down the standoffs slightly. You could also choose shorter standoffs, but that risks running out of thread to engage when assembling the case.

### 5.5 Install 9mm standoffs on top PCB assembly and align with top sound plates

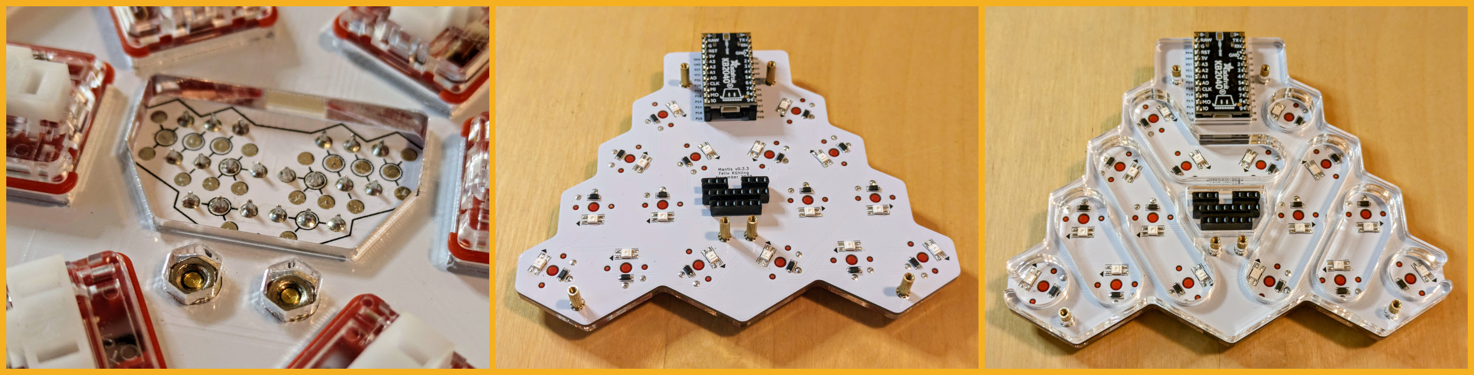
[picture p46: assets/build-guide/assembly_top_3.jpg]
Standoffs


The switch plates have small hexagonal holes that should hold M2 hex nuts. Screw the 9mm standoffs through the mounting holes of the top PCB into the hex nuts. Turn the PCB with the standoffs sticking up and lower the two upper sound plates. If necessary, loosen the standoffs and tighten them after placing the sound plates.

### 5.6 Align and connect bottom PCB assembly, install 3mm standoffs

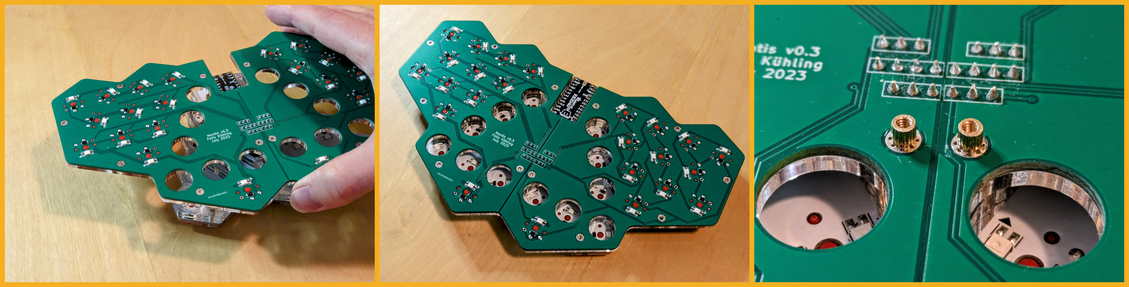
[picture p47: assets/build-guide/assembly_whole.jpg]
Stack bottom on top


Turn the bottom PCB assembly up-side-down and lower it onto the top PCB. Make sure it's properly aligned around the controller and the standoffs, and that the pins line up with the the headers on the top PCB. Screw the 3mm standoffs through the mounting holes into the 9mm standoffs.

Fasten the remaining six 3mm standoffs with hex nuts onto the bottom PCBs.

### 5.7 Test switches on bottom PCBs

Plug in the keyboard and use the Vial Matrix Tester to make sure all the switches are working before we close the case.

### 5.8 Align bottom switch plate and base plate, close the case

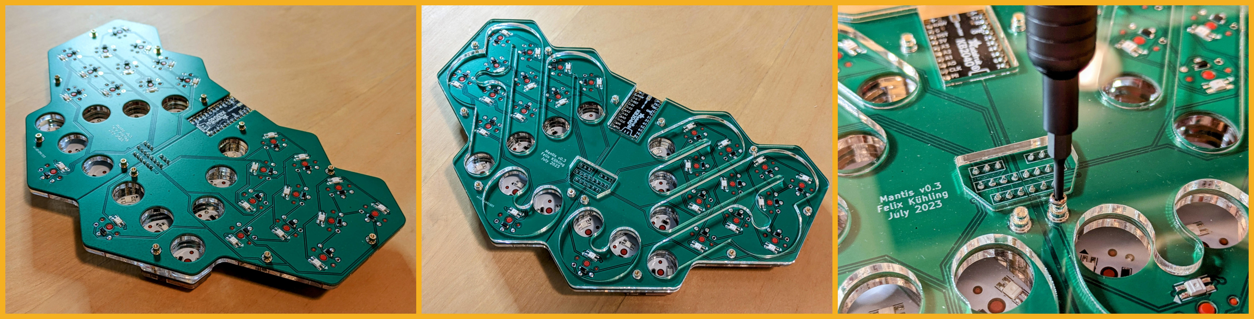
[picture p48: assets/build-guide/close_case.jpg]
Case closed


Fit the bottom sound plate over the 3mm standoffs with the sharper edges towards the PCBs. Then add the base plate in the same way and close the case with 12 M2 screws.

### 5.9 Add Bumpers

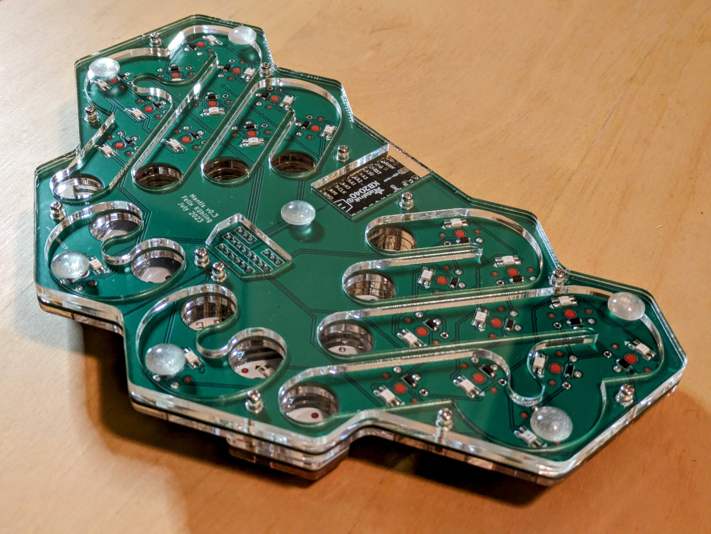
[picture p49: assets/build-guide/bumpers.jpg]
Bumpers
>

Stick some rubber bumpers on the bottom of the case at the corners and one in the middle to properly support the board when installing key caps.

### 5.10 Install key caps

During keycap installation be careful to align the pegs with the slots in the switch stems. Push down evenly to avoid breaking the pegs. If a key doesn't want to go in, check the pegs for any extra support material and file it off if necessary.

If you need to remove the keys later, use a key cap puller and pull up straight.

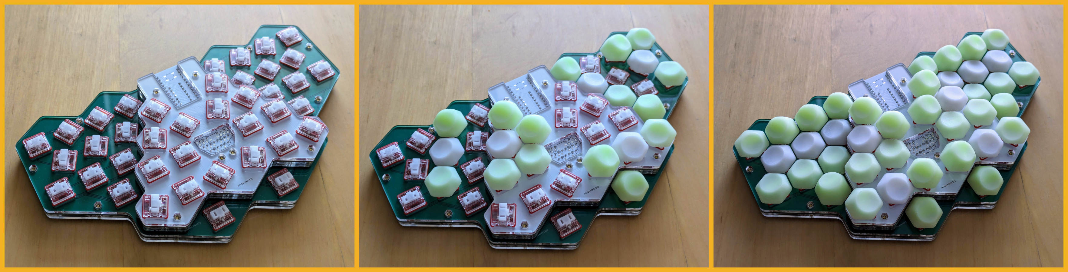
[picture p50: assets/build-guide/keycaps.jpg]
Keycap installation


The switches are rotated to give the right key profile with only one or two types of key caps. There are only two possible orientations for each key cap. If you're not sure what's the right orientation for each key, use the picture for reference.

To minimize finger movement, I recommend the taller keys in the top row (except the outer pinkie key), for the lower middle finger keys, and for the four innermost thumb keys.

## Done!

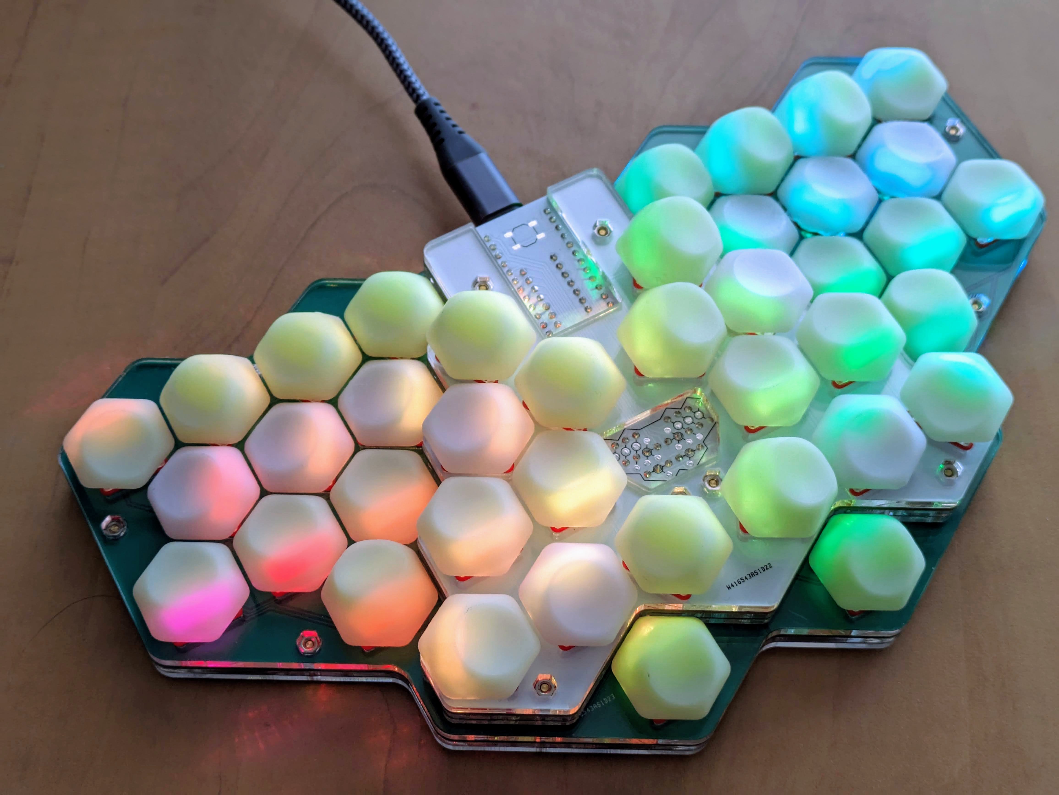
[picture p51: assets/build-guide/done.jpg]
Done
>

Congratulations on your new Mantis keyboard. I hope you will enjoy using it as much as I do!

## Appendix

### Using 8mm headers

Normal 8mm headers aren't really 8mm. If you add up the male and female side, they are about 10.5mm. That's more than the 9mm between the top and bottom PCBs that works with my choice of case plates and standoffs.

The cleanest solution is to use short 5mm headers that add up to 7.5mm. When the keyboard is assembled, the pins won't be inserted all the way. But they get inserted far enough to make a good connection. However, I have only seen 5mm headers sold by Adafruit. It's much easier to get normal 8mm headers from many sources. Here is how to make those work.

Use the female side as normal. On the male side, push the pins of the headers all the way through the plastic piece so that one end of the pin (formerly the top end) is flush with the plastic. Then insert this modified header from the opposite side of the PCB. Then solder the long pins sticking through the PCB. Be careful to avoid thick solder blobs sticking up too far, because that would make the pins hard to insert into the female side. This trick works both for the male headers in the bottom Mantis PCB, and for the controller pins.

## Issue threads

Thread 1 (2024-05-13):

I really love your project.

inanmb, 2024-05-13:
Hi! I really love your project, this is really a piece of art 💜 Would you ever consider selling one of them? I'm so fascinated that I regularly check the project updates. Your work is amazing 🙏

fxkuehl, 2024-05-13:
Hi, thank you for your interest and praise. At the moment I'm just doing this as a hobby project on the side. I'm not set up as a business to produce and ship kits or complete keyboards. The current design also takes too much manual labor for small-series production. I'd like get back to designing the next version to take advantage of PCB-assembly, maybe integrate the controller, try out a different case design and mounting style and add a pointing device, maybe with a VIK module.

I do have some left-over parts from the builds I made for family and friends. If you're interested, I could send you an incomplete kit or just the PCBs. As a one-off I would also consider building another complete keyboard for a fee. I'd need to order some more parts that I ran out of (switches, level shifter, 3D printed keycaps, M2 hardware).

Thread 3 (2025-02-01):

ZMK Support

Silcantar, 2025-02-01:
Not an issue, I just wanted to let you know that I created [a ZMK module](https://github.com/Silcantar/zmk-mantis) that adds support for the Mantis in that firmware. Feel free to add a link to it here if you like.

I also created some 3d printed case files. Not sure if that's something you'd be interested in having contributed to the project. I'm fairly new to the Git ecosystem so I'm not sure of the etiquette of submitting a pull request, especially to a single-contributor project.

Finally, a question: have you tried putting the higher keycaps on the lower inner index finger keys (QWERTY G and H)? I haven't tried it yet (just finished my Mantis today) but it feels like they might be more comfortable (at least for me) that way.

My Mantis, with the 3d printed case:
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

fxkuehl, 2025-02-01:
Wow, that looks great! Thank you for sharing. This is the first picture I've seen of a Mantis in the wild that I have not built myself. I hope you'll enjoy it a lot. I see you also added a screen. Your key caps look very smooth. What's the material and print process you used?

I will add a link to your ZMK shield to my documentation so others can find it and give it a try.

I wouldn't mind adding your case files to my repository, maybe in a new top-level folder "case". Feel free to create a pull request for the main branch.

I have tried using the taller keys on the lower/inner index finger keys. Personally I didn't like it because it creates a step that the index finger has to climb from V to G or M to H. BTW, I'm working on a cylindrical/saddle shaped key profile. Would you be interested in being a Beta tester? ;)

Silcantar, 2025-02-03:
I just had JLCPCB print the caps when I ordered the PCBs. They're 9600 resin, spray painted matte black/green by them.

I added the screen because I omitted the LEDs to conserve power but still wanted to have an indication of the layer/battery/Bluetooth state. Since the Nice!View has the same footprint as a Pro Micro it fits very nicely in the opening in the upper plate.

fxkuehl, 2025-03-08:
I thought more about how to put taller keycaps on the bottom inner index finger keys. I experimented with different keycap rotations with some custom keycaps I had printed a long time ago. I found a configuration that is more comfortable. After getting used to this at home for a week, converting my office keyboard today felt like a definite improvement. I will use this configuration on Mantis v1.0.

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
_Never mind the mixed colors, I was using this experiment to also try out different materials back when I had these printed_

You can convert your keyboard to this layout with some custom-rotated keycaps. You can generate them from the keycap.scad model by setting $rot=60 or $rot=120 respectively to rotate the stem relative to the keycap surface. You'll need two of each. Other parameters for the tall solid keycaps should be $tilt=28, $rise=2.9, $rgb=false, $fa=1.

Closed 2025-02-02.

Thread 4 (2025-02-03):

[feature request] 6 additional buttons

bemyak, 2025-02-03:
Hi!

I absolutely love the concept of mantis. I was pondering the idea of hexagonal keys for a while and was delighted to find that this project already exists and is so well though through!

I'm considering making a build of my own, but I would need to somehow add these 6 keys:

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

The new keys under pinkies and thumbs are within one hop from the resting position of the fingers, so, in my opinion, it's a missed opportunity to leave these sweet spots vacant. Because of RSI, I try to move all modifier keys to the thumb cluster and having 6 buttons there is essential to me. The button under pinkie would be a handy layer switcher.

The new keys under the ring fingers are within two hops from the resting position, so it's more arguable, but it mirrors the keys under index fingers and makes the layout quite similar to Dactyl Manuform.

Do these changes make sense to you? If so, would you consider incorporating them into the build, or at least give me some guidance on how to do it on my own?

Thank you again for the amazing project!

bemyak, 2025-02-03:
Thank you for the info! I didn't know about Ergogen, I'll explore it more. Let's see where it leads me :)

Feel free to close this issue if it is not aligned with the future of Mantis.

fxkuehl, 2025-02-08:
I was curious what a 46-key Mantis version would look like and created a WIP branch for it. I was worried it would end up looking too chubby, but I'm happy to say it still looks like a Mantis:
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

I only updated the ergogen file. I don't plan to develop this further, but I'll leave it as a starting point for you or others. If you want to develop this into a real keyboard, a lot of work remains to create the PCBs and firmware:
- Update controller pin assignment to connect the extra row
- Update header footprints to add an extra row pin
- Update connect_leds.awk to handle the additional LEDs
- Generate PCBs, update footprints, route traces, etc.
- Update QMK firmware to handle the extra keys and LEDs

Closed 2025-02-08.

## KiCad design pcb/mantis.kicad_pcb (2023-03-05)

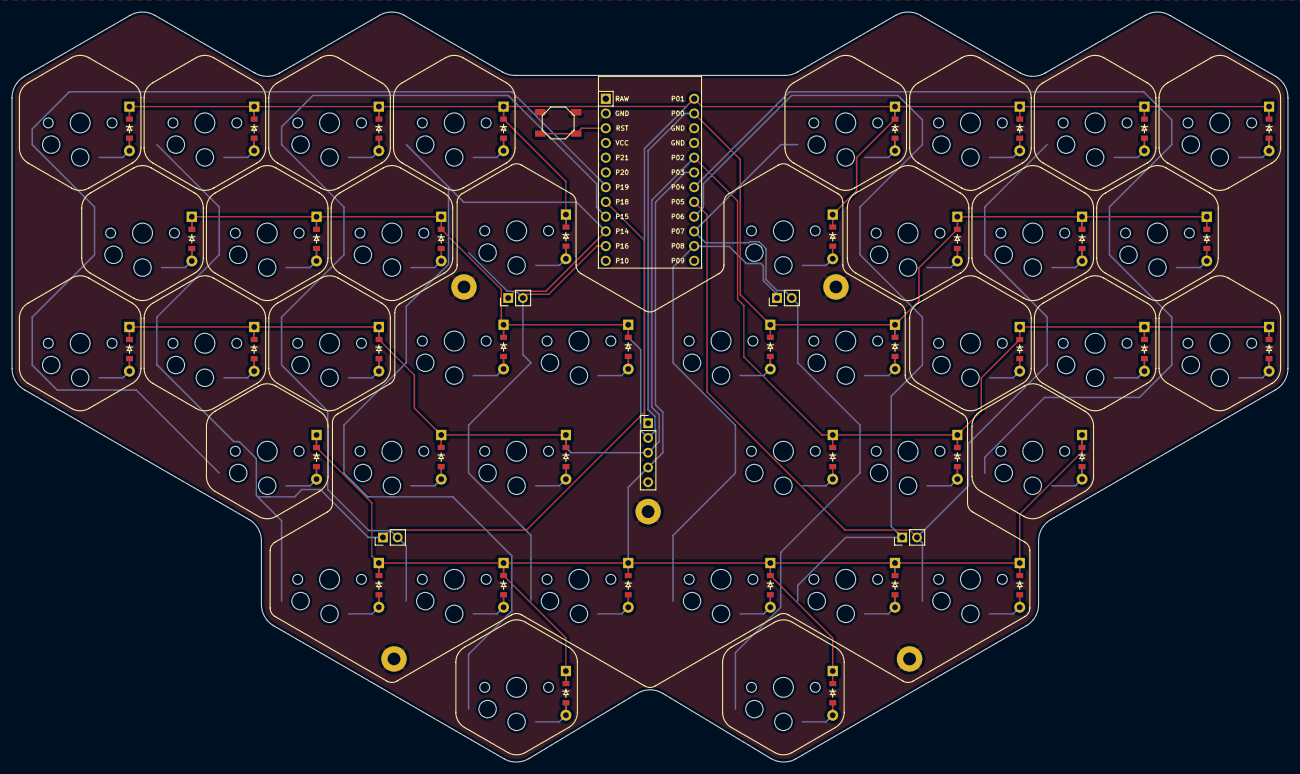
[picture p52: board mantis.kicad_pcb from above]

Board: 2 copper layers, 220.0 x 129.3 mm, 82 parts (0 on the bottom side), 56 nets.

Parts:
B1: SW_TACT_ALPS_SKQGABE010
D1, D2, D3, D4, D5, D6, D7, D8, D9, D10, D11, D12, D13, D14, D15, D16, D17, D18, D19, D20, D21, D22, D23, D24, D25, D26, D27, D28, D29, D30, D31, D32, D33, D34, D35, D36, D37, D38, D39, D40: ComboDiode
MCU1: ProMicro
S1, S2, S3, S4, S5, S6, S7, S8, S9, S10, S11, S12, S13, S14, S15, S16, S17, S18, S19, S20, S21, S22, S23, S24, S25, S26, S27, S28, S29, S30, S31, S32, S33, S34, S35, S36, S37, S38, S39, S40: PG1350

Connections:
GND: B1.1, MCU1.2, MCU1.15, MCU1.16
P0: D2.1, D5.1, D8.1, D11.1, D14.1, D22.1, D25.1, D28.1, D31.1, D34.1, MCU1.14
P1: D3.1, D6.1, D9.1, D12.1, D15.1, D23.1, D26.1, D29.1, D32.1, D35.1, MCU1.13
P2: D1.1, D4.1, D7.1, D10.1, D13.1, D21.1, D24.1, D27.1, D30.1, D33.1, MCU1.17
P3: D16.1, D17.1, D18.1, D19.1, D20.1, D36.1, D37.1, D38.1, D39.1, D40.1, MCU1.18
P4: MCU1.19, S21.2, S22.2, S23.2, S36.2
P5: MCU1.20, S24.2, S25.2, S26.2, S37.2
P6: MCU1.21, S27.2, S28.2, S29.2, S38.2
P7: MCU1.22, S30.2, S31.2, S32.2, S39.2
P8: MCU1.23, S33.2, S34.2, S35.2, S40.2
P14: MCU1.10, S10.2, S11.2, S12.2, S19.2
P15: MCU1.9, S7.2, S8.2, S9.2, S18.2
P16: MCU1.11, S13.2, S14.2, S15.2, S20.2
P18: MCU1.8, S4.2, S5.2, S6.2, S17.2
P19: MCU1.7, S1.2, S2.2, S3.2, S16.2
RST: B1.2, MCU1.3
c1_r1: D1.2, S1.1
c1_r2: D2.2, S2.1
c1_r3: D3.2, S3.1
c1_rt: D16.2, S16.1
c1m_r1: D21.2, S21.1
c1m_r2: D22.2, S22.1
c1m_r3: D23.2, S23.1
c1m_rt: D36.2, S36.1
c2_r1: D4.2, S4.1
c2_r2: D5.2, S5.1
c2_r3: D6.2, S6.1
c2_rt: D17.2, S17.1
c2m_r1: D24.2, S24.1
c2m_r2: D25.2, S25.1
c2m_r3: D26.2, S26.1
c2m_rt: D37.2, S37.1
c3_r1: D7.2, S7.1
c3_r2: D8.2, S8.1
c3_r3: D9.2, S9.1
c3_rt: D18.2, S18.1
c3m_r1: D27.2, S27.1
c3m_r2: D28.2, S28.1
c3m_r3: D29.2, S29.1
c3m_rt: D38.2, S38.1
c4_r1: D10.2, S10.1
c4_r2: D11.2, S11.1
c4_r3: D12.2, S12.1
c4_rt: D19.2, S19.1
c4m_r1: D30.2, S30.1
c4m_r2: D31.2, S31.1
c4m_r3: D32.2, S32.1
c4m_rt: D39.2, S39.1
c5_r1: D13.2, S13.1
c5_r2: D14.2, S14.1
c5_r3: D15.2, S15.1
c5_rt: D20.2, S20.1
c5m_r1: D33.2, S33.1
c5m_r2: D34.2, S34.1
c5m_r3: D35.2, S35.1
c5m_rt: D40.2, S40.1

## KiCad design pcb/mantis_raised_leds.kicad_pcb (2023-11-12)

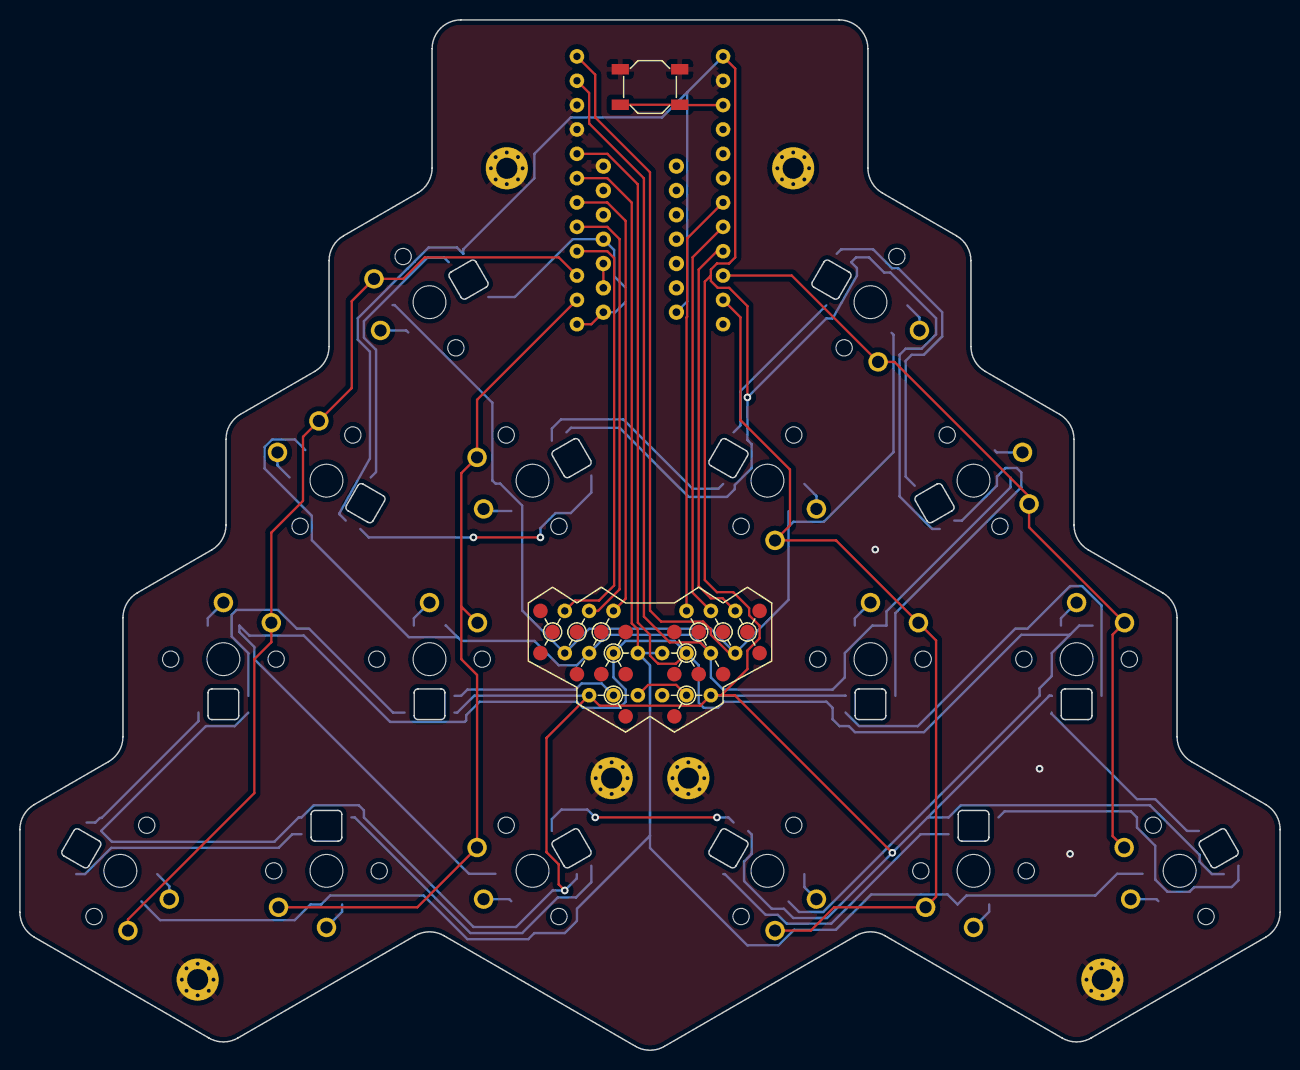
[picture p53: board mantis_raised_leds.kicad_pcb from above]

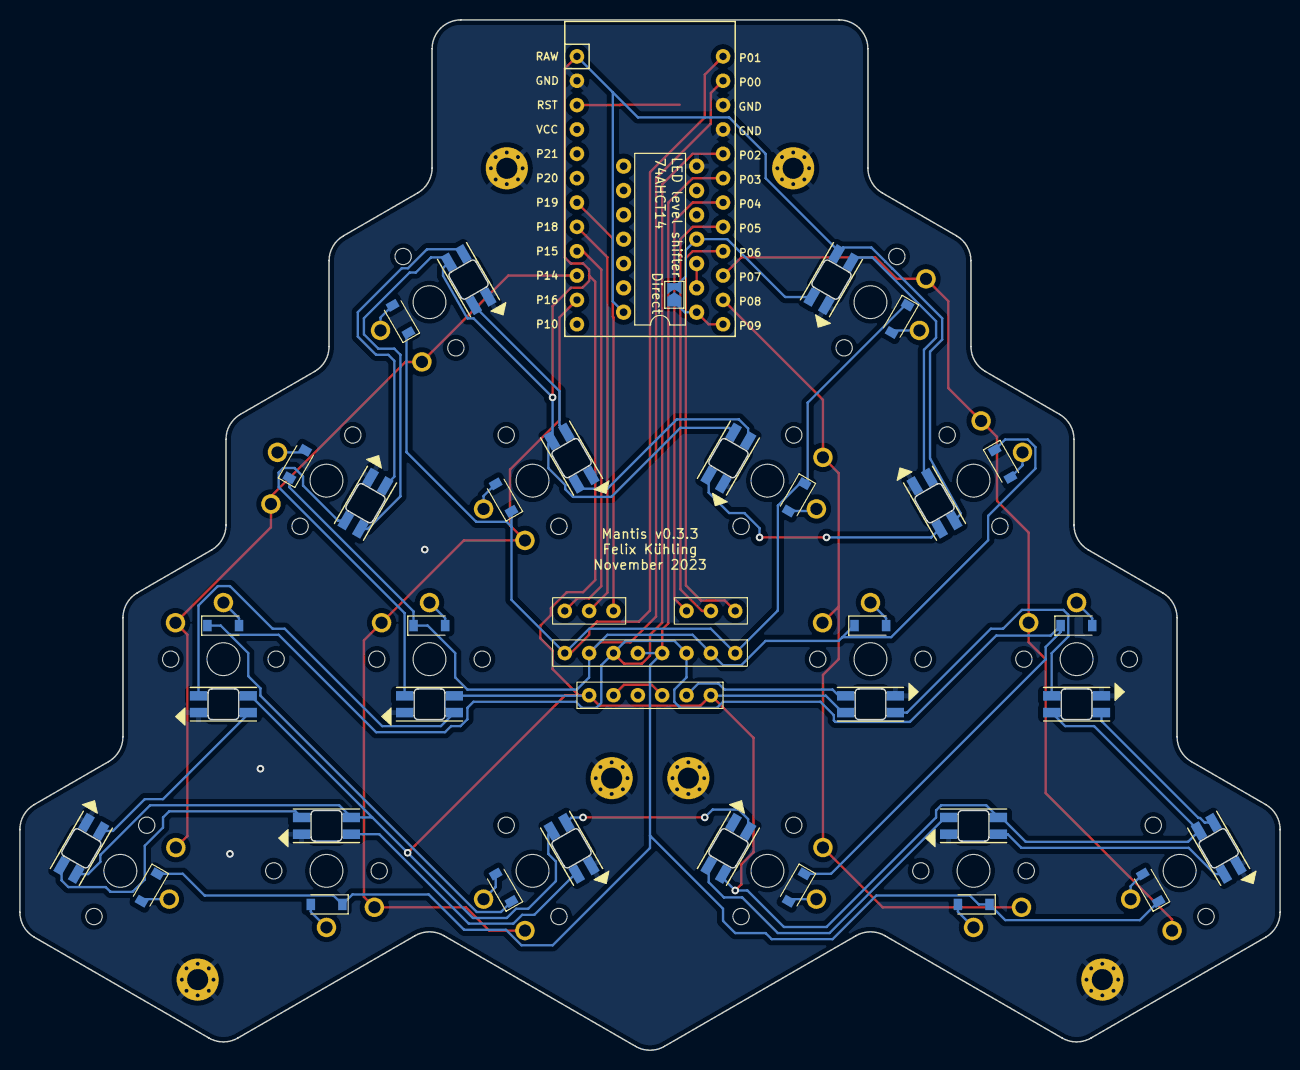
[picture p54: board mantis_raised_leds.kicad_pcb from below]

Board: 2 copper layers, 131.5 x 107.5 mm, 59 parts (2 on the bottom side), 52 nets.

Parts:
B1: SW_TACT_ALPS_SKQGABE010
D1, D2, D3, D4, D5, D6, D7, D8, D9, D10, D11, D12, D13, D14, D15, D16: SOD123-back
Direct: SolderJumper-2_P1.3mm_Open_TrianglePad1.0x1.5mm
LED1, LED2, LED3, LED4, LED5, LED6, LED7, LED8, LED9, LED10, LED11, LED12, LED13, LED14, LED15, LED16: SK6812_MINI-E-back
LED level shifter: DIP-14_W7.62mm
MCU1: ProMicro-back
MCU2: Connector-20pin
PAD1, PAD2, PAD3, PAD4, PAD5, PAD6: MountingHole_2.2mm_M2_Pad_Via
S1, S2, S3, S4, S5, S6, S7, S8, S9, S10, S11, S12, S13, S14, S15, S16: PG1350

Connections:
C1: MCU1.19, MCU2.19
C2: MCU1.20, MCU2.20
C3: MCU1.21, MCU2.21
C4: MCU1.22, S1.1, S3.1, S5.1, S7.1
C5: MCU1.23, S2.1, S4.1, S6.1, S8.1
GND: B1.1, LED1.3, LED2.3, LED3.3, LED4.3, LED5.3, LED6.3, LED7.3, LED8.3, LED9.3, LED10.3, LED11.3, LED12.3, LED13.3, LED14.3, LED15.3, LED16.3, LED level shifter.7, MCU1.2, MCU1.15, MCU1.16, PAD1.1, PAD2.1, PAD3.1, PAD4.1, PAD5.1, PAD6.1
LED: Direct.1, LED level shifter.1, MCU1.24
M_C1: MCU1.7, MCU2.7
M_C2: MCU1.8, MCU2.8
M_C3: MCU1.9, MCU2.9
M_C4: MCU1.10, S9.1, S11.1, S13.1, S15.1
M_C5: MCU1.11, S10.1, S12.1, S14.1, S16.1
R1: D5.1, D6.1, D13.1, D14.1, MCU1.17, MCU2.10, MCU2.17
R2: D3.1, D4.1, D11.1, D12.1, MCU1.14, MCU2.6, MCU2.14
R3: D1.1, D2.1, D9.1, D10.1, MCU1.13, MCU2.5, MCU2.13
RST: B1.2, MCU1.3
RT: D7.1, D8.1, D15.1, D16.1, MCU1.18, MCU2.11, MCU2.18
VCC: LED1.1, LED2.1, LED3.1, LED4.1, LED5.1, LED6.1, LED7.1, LED8.1, LED9.1, LED10.1, LED11.1, LED12.1, LED13.1, LED14.1, LED15.1, LED16.1, LED level shifter.14, MCU1.1, MCU2.4, MCU2.22
c4_r1: D5.2, S5.2
c4_r2: D3.2, S3.2
c4_r3: D1.2, S1.2
c4_rt: D7.2, S7.2
c5_r1: D6.2, S6.2
c5_r2: D4.2, S4.2
c5_r3: D2.2, S2.2
c5_rt: D8.2, S8.2
di_c4_r1: LED5.4, LED7.2
di_c4_r2: LED1.2, LED3.4
di_c4_r3: Direct.2, LED1.4, LED level shifter.4
di_c4_rt: LED7.4, LED8.2
di_c5_r1: LED6.4, LED14.2
di_c5_r2: LED4.4, LED5.2
di_c5_r3: LED2.4, LED3.2
di_c5_rt: LED6.2, LED8.4
di_mirror_c3_r3: MCU2.12, MCU2.24
di_mirror_c4_r1: LED12.2, LED13.4
di_mirror_c4_r2: LED9.2, LED11.4
di_mirror_c4_r3: LED9.4, LED10.2
di_mirror_c4_rt: LED13.2, LED15.4
di_mirror_c5_r1: LED14.4, LED16.2
di_mirror_c5_r2: LED11.2, LED12.4
di_mirror_c5_r3: LED2.2, LED10.4
di_mirror_c5_rt: LED15.2, LED16.4
do_c5_r2: LED4.2, MCU2.23
mirror_c4_r1: D13.2, S13.2
mirror_c4_r2: D11.2, S11.2
mirror_c4_r3: D9.2, S9.2
mirror_c4_rt: D15.2, S15.2
mirror_c5_r1: D14.2, S14.2
mirror_c5_r2: D12.2, S12.2
mirror_c5_r3: D10.2, S10.2
mirror_c5_rt: D16.2, S16.2

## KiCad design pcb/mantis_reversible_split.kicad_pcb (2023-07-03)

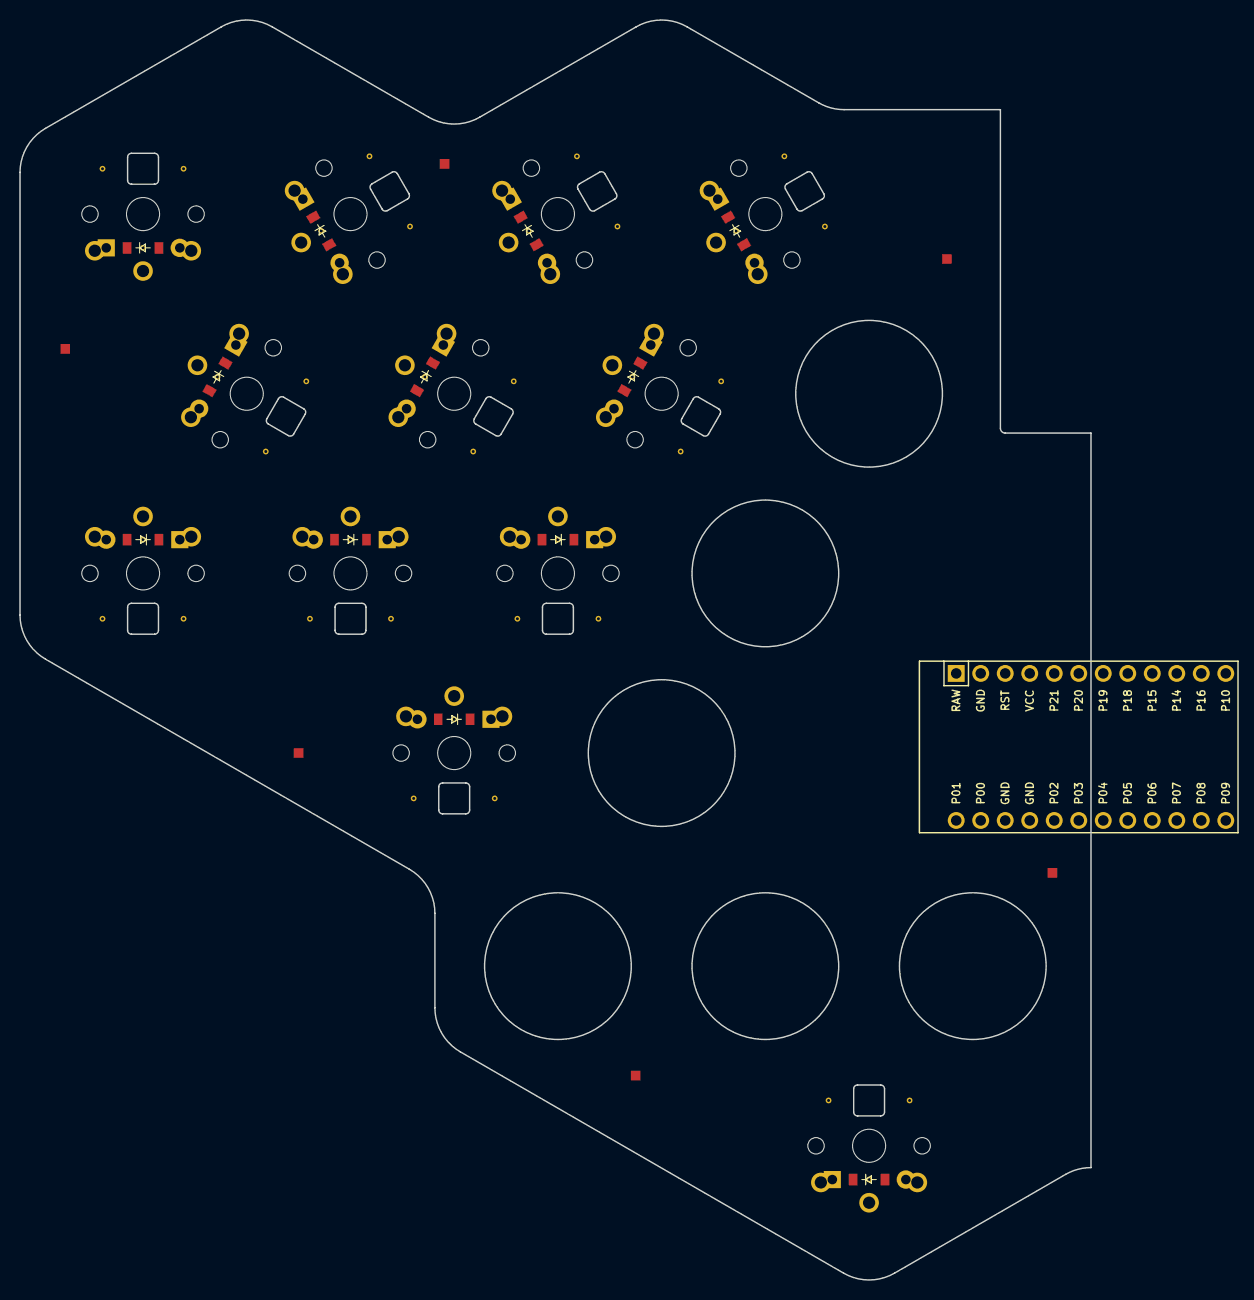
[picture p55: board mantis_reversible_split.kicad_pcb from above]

Board: 2 copper layers, 111.0 x 130.6 mm, 43 parts (0 on the bottom side), 45 nets, no tracks yet.

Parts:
D1, D2, D3, D4, D5, D6, D7, D8, D9, D10, D11, D12: ComboDiode
LED1, LED2, LED3, LED4, LED5, LED6, LED7, LED8, LED9, LED10, LED11, LED12: WS2812B
MCU1: ProMicro
PAD1, PAD2, PAD3, PAD4, PAD5, PAD6: SMDPad
S1, S2, S3, S4, S5, S6, S7, S8, S9, S10, S11, S12: PG1350

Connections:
C1: MCU1.19, S1.1, S4.1, S7.1, S10.1
C2: MCU1.20, S2.1, S5.1, S8.1, S11.1
C3: MCU1.21, S3.1, S6.1, S9.1, S12.1
GND: LED1.3, LED1.33, LED2.3, LED2.33, LED3.3, LED3.33, LED4.3, LED4.33, LED5.3, LED5.33, LED6.3, LED6.33, LED7.3, LED7.33, LED8.3, LED8.33, LED9.3, LED9.33, LED10.3, LED10.33, LED11.3, LED11.33, LED12.3, LED12.33, MCU1.2, MCU1.15, MCU1.16, PAD1.1, PAD2.1, PAD3.1, PAD4.1, PAD5.1, PAD6.1
R1: D7.1, D8.1, D9.1, MCU1.17
R2: D4.1, D5.1, D6.1, MCU1.14
R3: D1.1, D2.1, D3.1, MCU1.13
RT: D10.1, D11.1, D12.1, MCU1.18
VCC: LED1.1, LED1.11, LED2.1, LED2.11, LED3.1, LED3.11, LED4.1, LED4.11, LED5.1, LED5.11, LED6.1, LED6.11, LED7.1, LED7.11, LED8.1, LED8.11, LED9.1, LED9.11, LED10.1, LED10.11, LED11.1, LED11.11, LED12.1, LED12.11, MCU1.4, MCU1.22
c1_r1: D7.2, S7.2
c1_r2: D4.2, S4.2
c1_r3: D1.2, S1.2
c1_rt: D10.2, S10.2
c2_r1: D8.2, S8.2
c2_r2: D5.2, S5.2
c2_r3: D2.2, S2.2
c2_rt: D11.2, S11.2
c3_r1: D9.2, S9.2
c3_r2: D6.2, S6.2
c3_r3: D3.2, S3.2
c3_rt: D12.2, S12.2
di_c1_r1: LED7.4, LED7.44
di_c1_r2: LED4.4, LED4.44
di_c1_r3: LED1.4, LED1.44
di_c1_rt: LED10.4, LED10.44
di_c2_r1: LED8.4, LED8.44
di_c2_r2: LED5.4, LED5.44
di_c2_r3: LED2.4, LED2.44
di_c2_rt: LED11.4, LED11.44
di_c3_r1: LED9.4, LED9.44
di_c3_r2: LED6.4, LED6.44
di_c3_r3: LED3.4, LED3.44, MCU1.23
di_c3_rt: LED12.4, LED12.44
do_c1_r1: LED7.2, LED7.22
do_c1_r2: LED4.2, LED4.22
do_c1_r3: LED1.2, LED1.22
do_c1_rt: LED10.2, LED10.22
do_c2_r1: LED8.2, LED8.22
do_c2_r2: LED5.2, LED5.22
do_c2_r3: LED2.2, LED2.22
do_c2_rt: LED11.2, LED11.22
do_c3_r1: LED9.2, LED9.22
do_c3_r2: LED6.2, LED6.22
do_c3_r3: LED3.2, LED3.22
do_c3_rt: LED12.2, LED12.22, MCU1.24

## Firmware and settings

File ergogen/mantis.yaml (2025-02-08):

units:
  # Hex key spacing
  hx: 21.5
  hy: 18.62
  # Margin around the PCB
  mx: 2
  my: 1.1547mx
  # Distance between key clusters
  dx: 3
  dy: 1.1547dx
  # Space around keys and fillet radius
  kx: 0.54/2
  ky: 1.1547kx
  fk: 3
  # Space around raised PCB and fillet radius
  rx: kx
  ry: 1.1547rx
  # Width of the sound channel and exit radius
  wc: 15.2
  # MCU vertical offset
  mcu_top: hy/3+2my
  # Gap between plates
  gap: 1

points:
  zones:
    # Just key positions for reference, without any rotation
    # Origin aligns the center/split line with both inch and mm rasters
    f:
      anchor:
        shift: [254-9hx/2-dx/2, -127+3hy]
      columns:
        c0:
          rows:
            r0: $unset
            r1: $unset
            r2: $unset
            r3:
              shift: [0]
        c1:
          rows:
            r0: $unset
          key:
            stagger: -2hy
            spread: 0
        c2:
          rows:
            r0: $unset
        c3:
          rows:
            r1:
              shift: [hx/2]
          key:
            stagger: -hy
            spread: hx/2
        c4:
          rows:
            r0: $unset
        c5:
          rows:
            r0: $unset
            r1: $unset
            r2:
              shift: [0]
      rows:
        r0:
        r1:
        r2:
          shift: [hx/2]
        r3:
          shift: [hx/2]
    t:
      anchor:
        shift: [254-5hx/2-dx/2, -127-hy-dy]
      columns:
        c1:
        c2:
        c3:
          rows:
            r1:
            r2:
              shift: [hx/2]
          key:
            stagger: -hy
            spread: hx/2
      rows:
        r1:

    # Positions for standoffs, mounting holes and headers
    mount:
      anchor:
        ref: f_c0_r3
      columns:
        base1:
          #rows.r.shift: [-hx+hx/4, -2hy]
          rows.r.shift: [-hx+hx/4, -3hy+hy/2]
        #base2:
        #  rows.r.shift: [hx+hx/8, -4hy+hy/4]
        base3:
          rows.r.shift: [hx/2, -hy/3]
        raise1:
          rows.r.shift: [2hx-9hx/32, -5hy-dy+7hy/16]
        raise2:
          rows.r.shift: [9hx/2+dx/2-4, -11hy/3]
        raise3:
          rows.r.shift: [4hx-hx/8, -hy/4]
        header:
          rows.r.shift: [9hx/2+dx/2, -3hy-dy/4+1.5]
      key:
        spread: 0

    # Keys are rotated in 60° increments to make a simulated key well
    # with sculpted key caps. Define each row in its own zone to make
    # the key rotation easier. Otherwise the spread and stagger get very
    # confusing. The matrix is a little unintuitive to minimize the
    # number of column pins between top and bottom PCBs.
    top:
      anchor:
        ref: f_c1_r3
      columns:
        c1:
          key:
            column_net: C1
            mirror.column_net: M_C1
        c2:
          key:
            column_net: C2
            mirror.column_net: M_C2
        c3:
          key:
            column_net: C3
            mirror.column_net: M_C3
        c4:
          key:
            spread: hx/2
            stagger: -hy
            column_net: C4
            mirror.column_net: M_C4
        c5:
          key:
            spread: hx/2
            stagger: -hy
            column_net: C5
            mirror.column_net: M_C5
      rows:
        r3:
          row_net: R3
          rotate: -60
    home:
      anchor:
        ref: f_c1_r2
      columns:
        c1:
          key:
            column_net: C1
            mirror.column_net: M_C1
        c2:
          key:
            column_net: C2
            mirror.column_net: M_C2
        c3:
          key:
            column_net: C3
            mirror.column_net: M_C3
        c4:
          key:
            spread: hx/2
            stagger: -hy
            column_net: C4
            mirror.column_net: M_C4
        c5:
          rows.r2:
            rotate: 180
          key:
            spread: hx/2
            stagger: -hy
            column_net: C5
            mirror.column_net: M_C5
      rows:
        r2:
          row_net: R2
          rotate: -120
    bottom:
      anchor:
        ref: f_c1_r1
      columns:
        c1:
          key:
            column_net: C1
            mirror.column_net: M_C1
        c2:
          key:
            column_net: C2
            mirror.column_net: M_C2
        c3:
          key:
            column_net: C3
            mirror.column_net: M_C3
        c4:
          key:
            spread: hx/2
            stagger: -hy
            column_net: C4
            mirror.column_net: M_C4
        c5:
          rows.r1:
            rotate: -60
          key:
            spread: 1.5hx
            stagger: -hy-dy
            column_net: C5
            mirror.column_net: M_C5
      rows:
        r1:
          row_net: R1
          rotate: 180
    thumb:
      anchor:
        ref: f_c0_r3
      columns:
        c1:
          key:
            column_net: C1
            mirror.column_net: M_C1
        c2:
          rows.rt:
            rotate: 180
          key:
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

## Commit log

2023-02-20 Mantis v0.1
    Initial commit of Mantis v0.1 Ergogen design, PCB and documentation.
    [mantis.kicad_pcb, mantis.kicad_sch]
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2023-03-04 Update ergogen file for v0.2
    This is basically rewritten from scratch to work with updated ergogen
    syntax.
    The most obvious change from v0.1 is the stacked PCB for the central
    keys. This should put the central four columns in more comfortable reach
    of the index fingers with the hands in a slightly tented posture. It
    should also make the home position easier to find and maintain without
    homing bumps or ridges.
    The front thumb keys remain on the bottom PCB, which should lead to a
    natural motion of the thumb and create a better separation between thumb
    keys to avoid hitting two at once. It makes the inner-most thumb key
    usable.
    The bottom PCB still has footprints for all keys and diodes, so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
    [mantis.yaml]
2023-03-05 Mantis v0.2 PCBs
    PCBs for Mantis v0.2 ready for manufacturing. The two PCBs are connected
    with 2.54mm pitch headers. Optional M2 standoffs can de used to adjust
    the height or provide more mechanical stability if needed.
    The bottom PCB can be used to build a flat keyboard without the top PCB.
    [mantis.kicad_pcb, mantis_raised.kicad_pcb]
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2023-03-19 Add missing padding
    The default padding is 19mm, which happens to be just 0.38mm too much.
    Noticed it when playing with different key sizes.
    [mantis.yaml]
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2023-06-05 keycap: Added switch model
    Added model of Choc switch to check how the key fits over the keycap.
    Calculate the vertical offset of the key based on its geometry before
    adding the stem.
    Slightly increased height and reduced thickness to get better fit with
    15° tilt. With the correct offset, the tilt only adds about 2mm height
    compared to FK hex keycaps.
    [keycap.scad]
2023-06-08 keycap: add stem, use minkowski sum
    Used minkowski sum to create a key with constant wall thickness. Added
    stem. Changed some parameters.
    [keycap.scad]
2023-06-08 keycap: add rgb to new keycap
    Added RGB holes to the new minkowski-based keycap model. Vertical holes
    work well regardless of the tilt angle. With the holes roughly the size
    of the wall thickness, they provide mostly indirect light unless viewed
    from almost directly above.
    [keycap.scad]
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2023-06-10 keycap: optimize faces on the dish
    Reduce number of triangles towards the center of the dish.
    [keycap.scad]
2023-06-10 keycap: Rework parameters
    Use booleans. Add minkowski parameter to render the keycap with or
    without using minkowski sum. Remove tilt parameter from various modules
    and use $tilt instead.
    [keycap.scad]
2023-06-11 keycap: Remove unnecessary variables and parameters
    No need to duplicate file parameters in local variables or module
    parameters.
    [keycap.scad]
2023-06-11 keycap: render the keycap for faster preview
    Use render() to speed up preview of the keycap, especially with RGB.
    [keycap.scad]
2023-06-11 keycap: optimize for faster preview
    Disable Minkowsky by default. Use render only for switch+key to speed up
    the whole keyboard preview.
    Use fixed resolution of 7.5° for the inside of the key. This speeds up
    preview and Minkowski sum. The faceted look may even be interesting.
    [keycap.scad]
2023-06-11 ergogen: Add base plate
    Added a base plate. Corrected switch cutout dimensions.
    [mantis.yaml]
2023-06-12 keycap: Render the case with the Mantis preview
    Add .dxf files for all case plates and PCBs. Render extrusions to
    preview the case in an assembled or exploded view, with or without the
    switches and keys.
    [base.dxf, keycap.scad, main_split.dxf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]
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2023-06-12 keycap: Add STL model of the keycap
    Parameters:
    - Key width: 20.96mm
    - Dish size: 14.0 mm
    - Slope: 15°
    - Tilt: 15°
    - Excentric: 2.0 mm
    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
    [keycap.stl]
2023-06-16 keycap: Add parameter for mid layer height
    Affects how far the central keys are raised.
    [keycap.scad]
2023-06-18 keycap: Speed up rendering of switches
    Use render() to speed up rendering of the differences.
    [keycap.scad]
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2023-06-19 keycap: Fix preview_switch_key with explode
    Make the box large enough to fit the keycap with explode.
    [keycap.scad]
2023-06-19 keycap: Fix artefacts in sliced key view
    Use render to fix artefacts. Show only half the key to reduce
    compiliation time and provide a better view of the interior.
    [keycap.scad]
2023-06-23 keycap: Move some helpers to a separate file
    Move helper functions to utils.scad. Add helper module for a
    half-sphere with optimized triangle count.
    [keycap.scad, utils.scad]
2023-06-23 keycap: Improve accuracy of Minkowski sums
    Use more accurate primitives. Use half-sphere module to mitigate the
    slow-down.
    [keycap.scad]
2023-06-23 keycap: Refactor stem
    Make whole stem a module to reuse in both minkey and difkey.
    [keycap.scad]
2023-06-23 keycap: Round off stem base
    Looks better, avoids interference with the RGB holes, and reduces stress
    concentrations at the base of the thin pegs.
    [keycap.scad]
2023-06-23 keycap: Make roundede features more consistent
    Fixed issue with rounding of concave part of stem pegs. Make $fn
    consistent in all parts of the stem, with the pegs using half the
    value. Render with less rounding when rendering the key with the
    switch.
    [keycap.scad]
2023-06-23 keycap: Move keyboard model into its own scad file
    Cleand up some global variable names in the process.
    [keycap.scad, mantis.scad]
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2023-06-26 ergogen: Small adjustments
    Fix diameter of screw holes in the base plate.
    Expand the header cutout and move the headers up slightly to accommodate
    the Mantis graphic on the front silkscreen within the cutout.
    [mantis.yaml]
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2023-07-03 pcb: Add footprint library
    Custom footprints for controller, diodes, LEDs and headers. Header
    footprints are designed to replace ProMicro footprint placeholders
    placed by ergogen. Diodes and LEDs have bottom-mounted and reversible
    variants.
2023-07-03 pcb: New Raised PCB with LEDs
    Generated with Ergogen, updated with connect_leds.awk, footprints
    updated and traces routed with kicad.
    [mantis_raised.kicad_pcb, mantis_raised_leds.kicad_pcb]
2023-07-03 pcb: New split/reversible bottom PCB with LEDs
    Half-sized, reversible bottom PCB to reduce manufacturing cost.
    [mantis_reversible_split.kicad_pcb, mantis_reversible_split_leds.kicad_pcb]
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2023-07-04 keycap: Render PCBs properly in the Mantis model
    Use DXFs of various PCB layers to render the PCBs more realistically.
    Also updated the plate DXFs (header cutout and base plate screw hole
    diameter).
    [base.dxf, mantis.scad, mantis_raised_leds-B_Cu.dxf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]
2023-07-04 pcb: Remove duplicate pads
    Replace reversible switch footprint to remove duplicate pads.
    [mantis_reversible_split_leds-B_Cu.dxf, mantis_reversible_split_leds-B_Mask.dxf, mantis_reversible_split_leds-B_Silkscreen.dxf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]
2023-07-08 keycap: Improve choc stem interface
    Round off the inner wall of the prongs to the stem, use a larger radius.
    [keycap.scad]
2023-07-08 keycap: Improve choc switch model
    Straight and sloping sections in the top and bottom casing. Notches in
    the sides of the rim. Larger fillet radii and smoother rendering of the
    rounded corners. Thicker walls to align with the LED hole.
    Make it a Choc Red switch with a red stem.
    Make the cut transparent when rendering the switch+key.
    [keycap.scad]
2023-07-08 keycap: Consistent detail in keyboard model
    Use $fs to make the LOD of the keyboard more consistent in the plates,
    PCBs and switches.
    [mantis.scad]
2023-07-10 pcb: Minor fixes and cleanups
    Fix DRC warnings about silk screen intsecting edge cuts or solder mask.
    Minor routing cleanups.
    [mantis_raised_leds.kicad_pcb, mantis_reversible_split_leds.kicad_pcb]
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2023-07-15 plates: Add case plates for v0.3
    base.dxf, plate_main.dxf, plate_raised.dxf, sound_plate_main.dxf,
    sound_plate_raised.dxf are generated by Ergogen.
    mantis-1x-3mm-all.dxf and mantis-2x-3mm-all.dxf arrange the plates in a
    layout for production of one or two keyboards, miminizing waste. The
    raised sound plate is duplicated to allow ~9mm stand-off between the
    PCBs. Made in LibreCAD based on a template from
    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
    [base.dxf, mantis-1x-3mm-all.dxf, mantis-2x-3mm-all.dxf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]
2023-07-15 keycap: Use unsplit plates for mantis model
    Use unsplit plate and soundplate. Remove offset from all the plates
    except the PCBs. Reduce the offset.
    [mantis.scad, plate_main.dxf, plate_main_split.dxf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]
2023-07-26 ergogen: Minor tweaks to dimensions
    Tweak some dimensions for slightly tighter fit and slightly more
    material at the thinnest places of the switch plates.
    Hex nut cutouts from 4.2mm -> 4mm, fillet 1mm->0.6mm.
    Switch cutout fillet 0.4mm -> 0.6mm.
    Header cutout about 0.5mm narrower.
    [mantis.yaml]
2023-08-16 keycap: Minor update to stat printing
    Only print stat on the outer profile of the key. Add center Y and Z
    coordinates.
    [keycap.scad]
2023-08-16 keycap: Optimize shape of the outer key slope
    Make the outside slope at the rim steeper by inverting the parabola at
    the rear of the key cap. This less bulging shape should improve typing
    accuracy by minimizing the risk of accidentally hitting adjacent keys
    and by making the back and sides of the dish's rim more distinct.
    Fixed the calculation of the slope at the front of the key.
    [keycap.scad]
2023-08-18 keycap: Redefine key height parameters
    Instead of a key height, specify droop and rise separately. This makes
    it explicit, how far the stem is inserted into the key. Only use the
    automatic offset calculation to warn if this causes interference between
    the key and switch.
    In the mantis keyboard model, add parameters for key rise. Make the top
    outer pinky keys the same tilt and rise as the home row.
    For a proper keywell with 15° tenting, specify tilt2=28, rise2=2.9.
    [keycap.scad, mantis.scad]
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2023-09-18 keycap/utils: factor out function concentric_faces
    Can be used to generate faces for the half-sphere and the keycap dish.
    Also added scale_x helper function.
    [utils.scad]
2023-09-18 keycap: New way to generate constant wall thickness
    Minkowski sum creates broken geometry for concave objects, which causes
    problems when doing CSG with it. Added an offset parameter to module
    fillet_hexagon_cone and tried to generate an object with the walls moved
    evenly inwards by that amount. Had to fudge it a bit on the sides.
    Used that to create a new offsetkey module.
    Also attempted to improve difkey, with questionable success.
    [keycap.scad]
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2023-09-18 keycap: Improve RGB holes for taller keys
    Make the holes long enough to pentrate taller key caps.
    Move holes according to tilt and excentricity. Add extra holes for
    steeper key caps.
    Cut the holes before inserting the stem to avoid cutting the stem on
    tall key caps.
    [keycap.scad]
2023-09-19 keycap: Fix sliced-key for taller keys
    [keycap.scad]
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2023-10-16 keycap: Add support for stem rotation
    This allows experiments with different rotations for individual keys
    before redesigning the whole PCB.
    [keycap.scad]
2023-11-04 ergogen: Rotate inner-bottom index-finger key
    This avoids interference with other keys when using a tall keycap
    profile.
    [mantis.yaml]
2023-11-08 keycap: Add soft clamping in Z-direction
    Make tall key caps about 2mm flatter. The lower part of the dish is
    unchanged. The upper half gets distorted into a saddle shape. This is
    meant to reduce unintended binding of the switch when pushing the key
    off-center and makes the keyboard look and feel less jagged.
    [keycap.scad, utils.scad]
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2023-11-11 pcb: Update raised PCB for v0.3.3
    Changes since v0.3:
    - Rotated inner bottom index finger keys
    - Use RAW pin for LED power supply
    - Added optional level shifter on LED data pin to support 3.3V controllers
    (Using two channels on a 6 channel inverter that's available on
    AdaFruit, cheap enough and simpler than building something from
    discrete resistor and transistor)
    - Added jumper to bypass level shifter for 5V controllers
    - Moved ProMicro pin labels on silkscreen to the outside to make room for
    level shifter
    - Slightly increased silkscreen line widths on the mantis logo/headers
    - Fixed unused pad number on header footprint
    - Cleaned up some routing, removed two GND vias
    Signed-off-by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
    [mantis_raised.kicad_pcb, mantis_raised_leds.kicad_pcb]
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2023-12-10 keycap: Add latest STLs
    Add missing STLs for latest keycap versions with and without RGB holes,
    15° and 28°, single and 10 in one piece.
    [keycap-v2-15-solid.stl, keycap-v3-28.stl]
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
